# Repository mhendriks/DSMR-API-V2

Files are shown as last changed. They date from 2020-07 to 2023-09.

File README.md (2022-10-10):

</a>&nbsp;<a href="https://smart-stuff.nl/shop/" target="_blank">Buy P1 Dongle</a>

# NEW

Nu ook native ESPHome - Home Assistant integratie.
Inclusief hardware serial ondersteuning.

Er zijn hiermee meerdere keuzes mogelijk met deze hardware, namelijk:
1. DSMR-API software: met eigen opslag en web interface. ook via mqtt te koppelen met Home Assistant of andere smart home oplossingen Zie [manual/dsmr-api](manual/dsmr-api/README.md)
2. ESPHome: voor naadloze integratie met Home Assistant. Zie [manual/epshome](manual/esphome/README.md)
3. Tasmota: in ontwikkeling Zie [manual/tasmota](manual/tasmota/README.md)

# Slimmemeter P1 Dongel - versie 3.7
Eigenschappen
- hardware design voor ESPhome + DSMR API
- gebruikt secundaire seriale hardware interface (UART1) voor de beste performance
- ESP-12F (4MB) als CPU Soc
- P1 signaal inversie via BJT transistor
- 6P6C (RJ12) socket voor gemakkelijke aansluiting
- usb micro connector voor externe voeding bij SMR 4.x/3.x/2.x meters en soms bij 5.x meters
- 2 diodes voor de USB/P1 return power beveiliging
- Primaire componenten op bovenkant van de pcb makkelijk voor de smt
-  LDO met een extreem laag verlies. Resultaat minder warmteafgifte en hogere betrouwbaarheid
- DTR signaal is altijd hoog
- optie om er een watermeter dongle van te maken
- optie om er een s0 dongle (pulsteller) van te maken

## SCHEMA
Op het printje zitten de volgende modules:
- voedingscircuit: een ultra low LDO spanningsregelaar zorgt er voor dat de 5Volt naar 3.3 omgezet wordt. 
- Dikke condensator voor het opvangen van de stroompieken tijden Wifi startup
- CPU: - ESP-12F 4Mb
- level shifter: om het P1 signaal te inverteren
- USB Power: om de p1 te kunnen voeden als paracitaire voeding (uit de p1) niet kan. Bijvoorbeeld bij SMR 2/3/4 meters of sommige 5.0 meters die heel gevoelig afgesteld zijn
- watermeter: klein circuit om watermeter sensor op aan te kunnen sluiten. Dit is een spanningsdeler. In de 3.5 versie komt hier een opto coupler voor in de plaats
- J2: om de dongle te kunnen programmeren
- J1: om de dongle aan te sluiten op de p1 poort van de slimme meter

Alle modules samen zie je in het onderstaande schema.
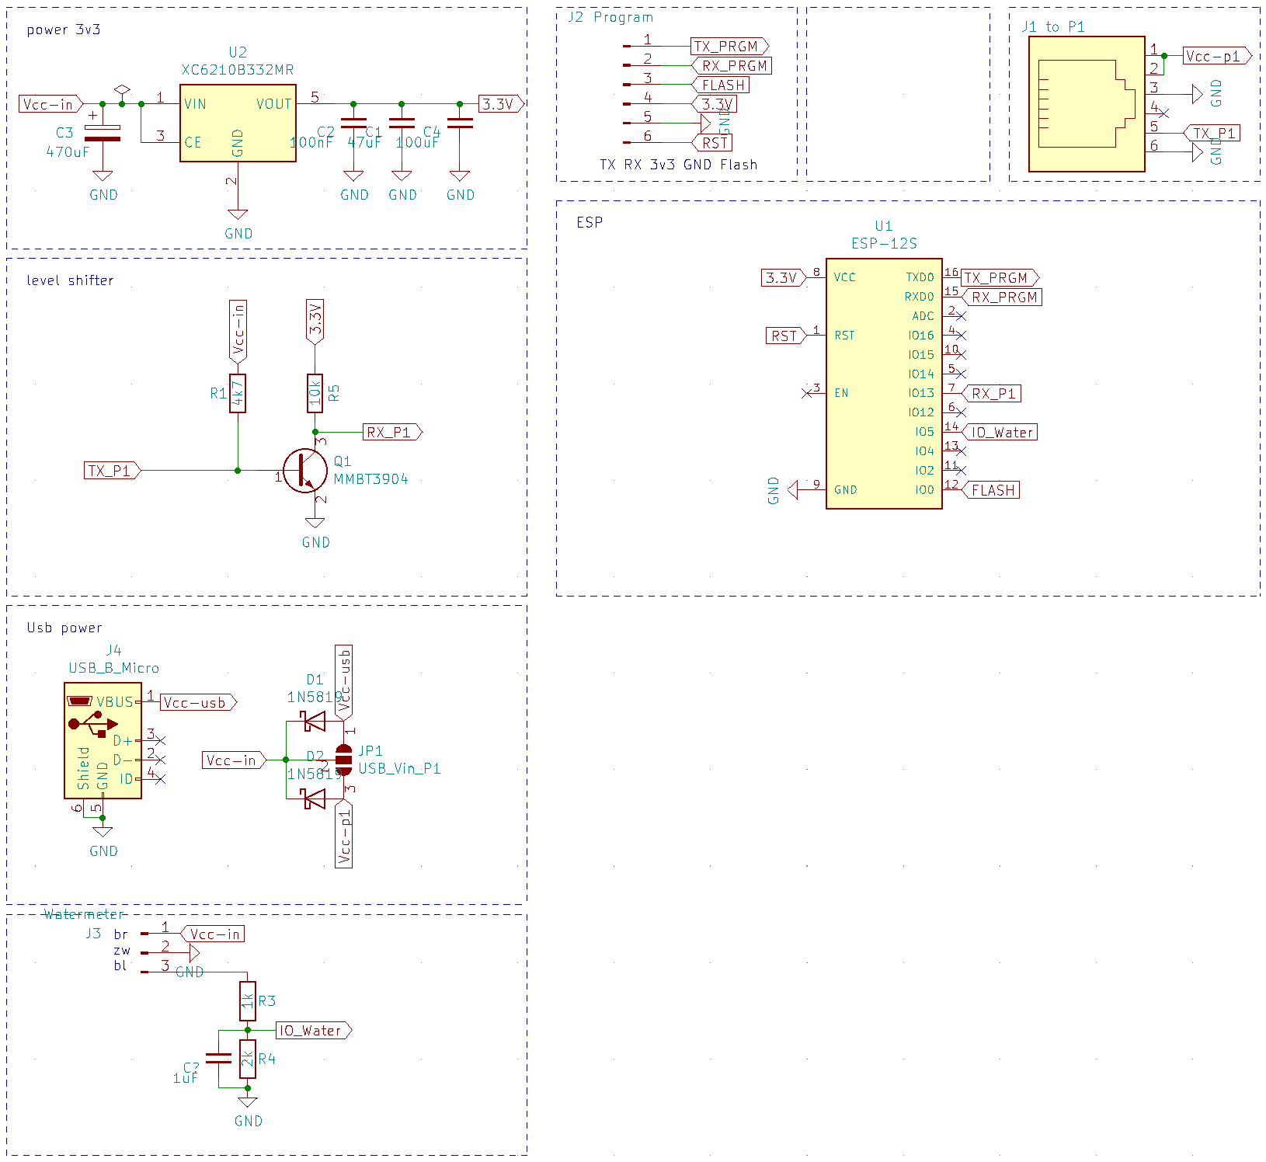
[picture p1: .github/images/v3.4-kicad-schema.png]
Kicad schema
 

Omgezet naar een pcb ziet dit er zo uit:

Bovenkant             |  Onderkant 
:-------------------------:|:-------------------------:
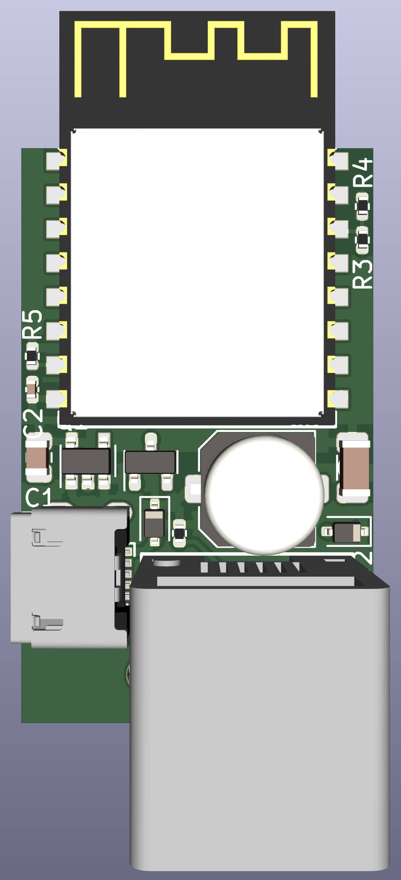
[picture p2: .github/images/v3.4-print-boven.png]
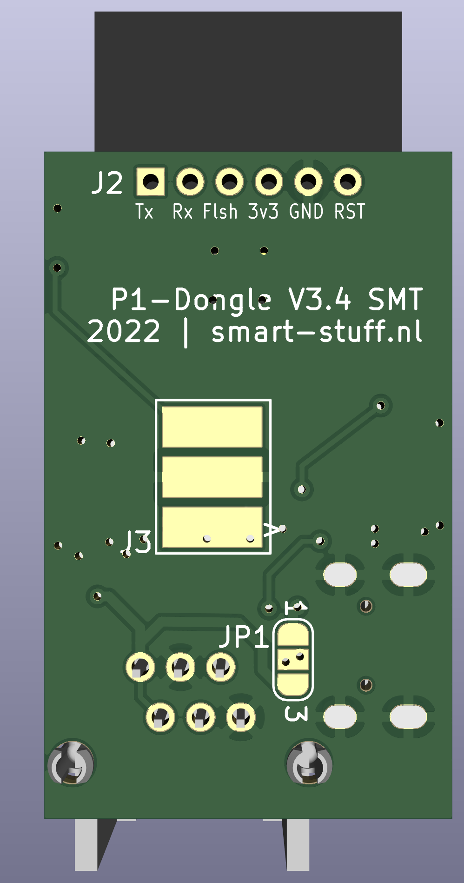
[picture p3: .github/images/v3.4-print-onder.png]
 |   

Afmeting van de print is 33 mm * 20 mm

## DSMR API SOFTWARE
Op basis van de DSMR API software van Willem aandeWiel is eerder al een doorvertaling gemaakt naar specifieke code voor de V2 en V3 hardware. Voor de V3.3 versie zijn er wederom aanpassingen gedaan met name vanwege het ontbreken van het DTR signaal. De code is hiervoor geoptimaliseerd.
Naar behoefte zou ook Tasmota of andere firmware gebruikt kunnen worden, dit is op de V3.3 versie verder niet uitgeprobeerd.

Aanpassing (tot nu toe) ten opzichte van DSMR-API van Willem zijn:
- alle statische pagina's komen uit een CDN (esp modules hebben maar een beperkte capaciteit en zijn geen hele goede webservers;)
- alle plaatjes zijn  iconen geworden en komen van een cdn
- files zijn omgezet naar Json zodat dit makkelijk te onderhouden en compacter is
- json API communicatie is ook gewijzigd (compacter en als een burst ipv gesegmenteerd)
- opmaak is zo veel als mogelijk uit de html / js files gehaald en in de css gestopt
- nieuw dashboard gemaakt
- Front-end settings worden van de dongel gelezen (een eerste aanzet)
- LittleFS in plaats van SPIFFS als bestandssysteem
- Home Assistant MQTT auto discovery 
- Watermeter uitbreiding

Uitgebreide documentatie is te vinden op: [Gitbook](https://docs.smart-stuff.nl/v/p1-dongle-api/)

## ESPHome SOFTWARE
Een hele eenvoudige manier om de dongle te koppelen aan Home Assistant is door middel van de ESPHome firmware + dsmr configuratie.
Belangrijkste voordeel is dan direct na het koppelen aan uw Wifi-netwerk begonnen kan worden met het toevoegen van de dongle in Home Assistant.

Hoe dit werkt en waar de yaml te vinden is kunt u hier lezen: [manual/esphome](manual/esphome/README.md)

# Hardware maken of aanschaffen
Je kan je eigen hardware maken of deze aanschaffen. Wil je deze aanschaffen neem dan een kijkje op <a href="https://smart-stuff.nl/shop/" target="_blank">smart-stuff.nl</a>

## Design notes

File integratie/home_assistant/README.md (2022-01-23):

# Home Assistant integratie

> LET OP! voor deze integratie dient een MQTT broker aanwezig te zijn in uw netwerk of in Home Assistant

HA maakt gebruik van de MQTT koppeling om de data vanuit de P1 dongel te ontvangen.
Om een koppeling te maken met HA dienen de volgende stappen doorlopen te worden.

>**HOME ASSISTANT AUTO DISCOVERY</br>**
> Vanaf firmware 3.2.2 is stap 1 & 2 niet meer nodig. De sensors worden automatisch door HA herkend.

1. Pas de configuration.yaml aan met extra sensors
2. Toevoegen van sensors.yaml
3. Voeg de MQTT integratie toe zodra deze niet bestaat
4. Naar behoefte dashboard + energie tabbladen configureren

**1. aanpassen configuration.yaml**</br>
Neem onderstaande code op in de `configuratie.yaml`

```
sensor: !include sensors.yaml
```

**2. Toevoegen van sensors.yaml**</br>
Voeg de `sensors.yaml` file in deze folder toe aan de HA configuratie waar ook de `configuratie.yaml` staat.

**3. Voeg de MQTT integratie toe zodra deze niet bestaat**</br>
Ga in HA naar Instellingen > Apparaten & Diensten en volg onderstaande stappen zodra MQTT integratie niet bestaat.</br>
Toevoegen MQTT integratie</br>
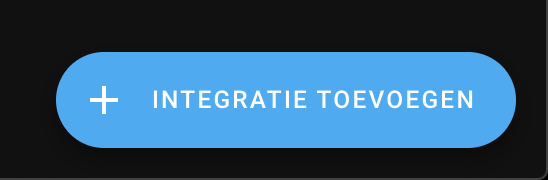
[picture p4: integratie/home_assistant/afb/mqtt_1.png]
<br>
Zoek op mqtt</br>
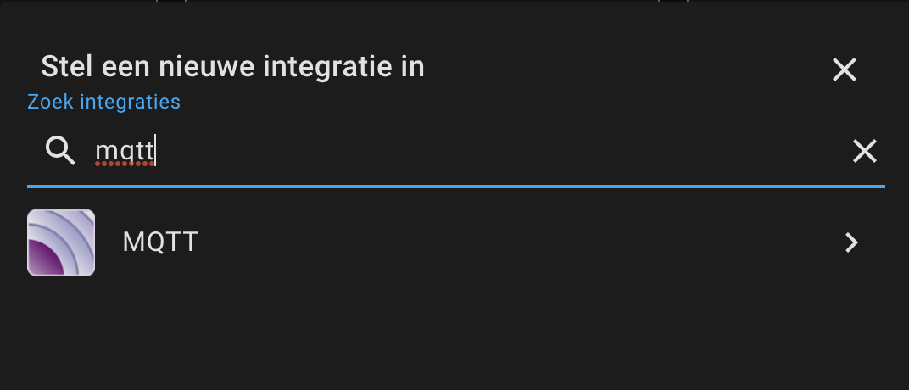
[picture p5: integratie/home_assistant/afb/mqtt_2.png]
<br>
Toevoegen broker naam/adres (192.168.2.250 is een voorbeeld)</br>
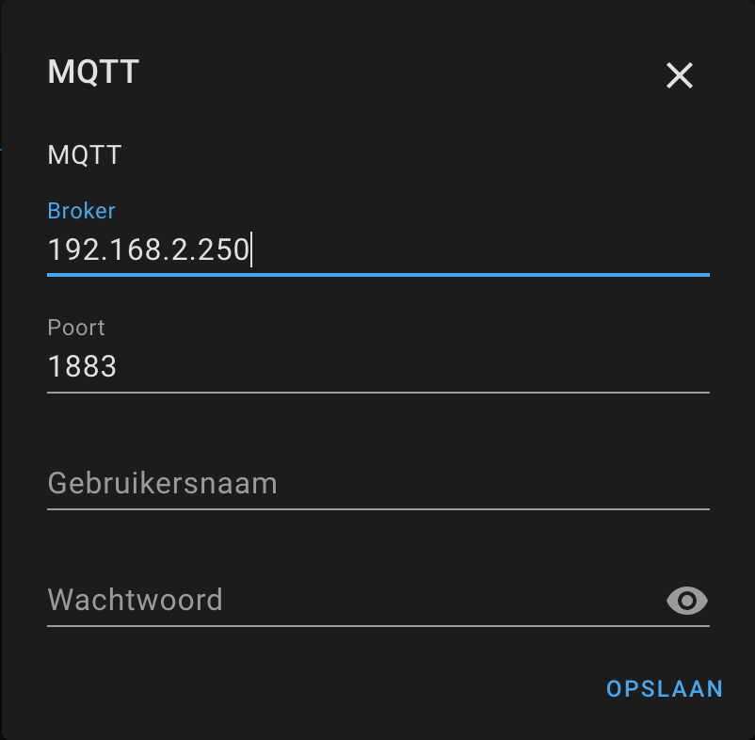
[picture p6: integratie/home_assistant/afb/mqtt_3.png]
<br>
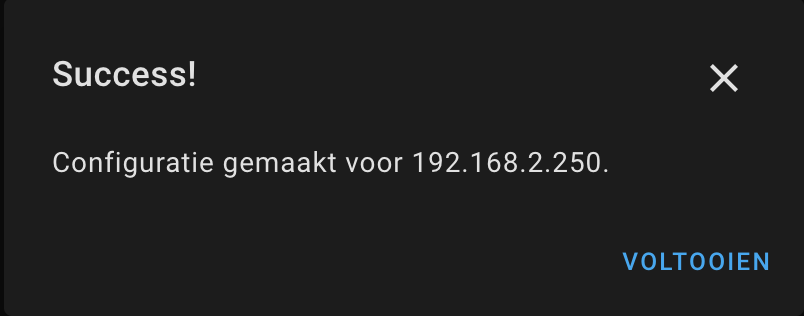
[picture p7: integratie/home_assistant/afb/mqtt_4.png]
<br>

**4. Naar behoefte dashboard + energie tabbladen configureren**</br>
Stel de verschillende tegels zelf samen en configureer de Energie tab op basis van de nieuwe entiteiten.</br>
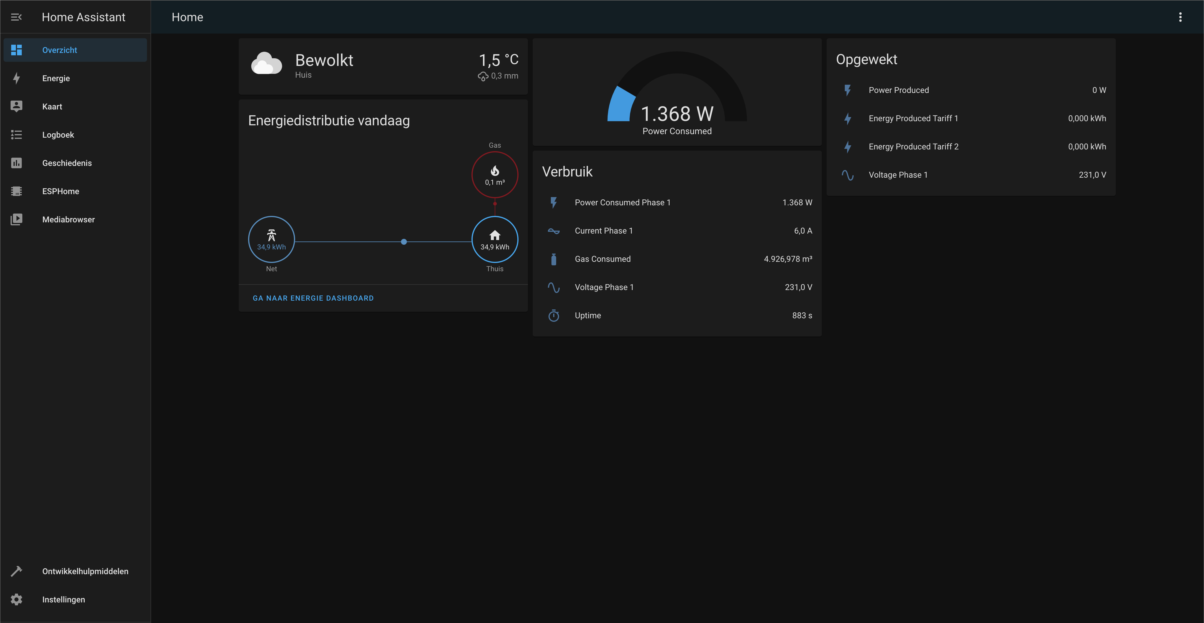
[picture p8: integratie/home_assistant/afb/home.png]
<br>

**Veel plezier met de dongle!**

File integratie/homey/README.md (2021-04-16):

# Homey integratie
Er is een Homey plugin om deze dsmr adapter op aan te sluiten deze is te vinden via: https://homey.app/nl-nl/app/com.p1.dsmr/P1-DSMR-Board-Lezer/
16-04-2021: is nu nog in testfase (https://homey.app/nl-nl/app/com.p1.dsmr/P1-DSMR-Board-Lezer/test/) en verwacht dat deze snel publiek beschikbaar komt.

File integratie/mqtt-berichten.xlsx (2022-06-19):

topic | payload
TOP TOPIC/identification | {identification":[{"value":"XMX5LGBBLA4412181356"}]}"
TOP TOPIC/p1_version | {p1_version":[{"value":"50"}]}"
TOP TOPIC/timestamp | {timestamp":[{"value":"210428201230S"}]}"
TOP TOPIC/equipment_id65] | {equipment_id":[{"value":"4530303435303033383833343439383137"}]}"
TOP TOPIC/energy_delivered_tariff1 | {energy_delivered_tariff1":[{"value":11741.29,"unit":"kWh"}]}"
TOP TOPIC/energy_delivered_tariff2 | {energy_delivered_tariff2":[{"value":12430.86,"unit":"kWh"}]}"
TOP TOPIC/energy_returned_tariff1 | {energy_returned_tariff1":[{"value":0,"unit":"kWh"}]}"
TOP TOPIC/energy_returned_tariff2 | {energy_returned_tariff2":[{"value":0,"unit":"kWh"}]}"
TOP TOPIC/electricity_tariff | {electricity_tariff":[{"value":"0002"}]}"
TOP TOPIC/power_delivered | {power_delivered":[{"value":0.703,"unit":"kW"}]}"
TOP TOPIC/power_returned | {power_returned":[{"value":0,"unit":"kW"}]}"
TOP TOPIC/voltage_l1 | {voltage_l1":[{"value":231,"unit":"V"}]}"
TOP TOPIC/current_l1 | {current_l1":[{"value":3,"unit":"A"}]}"
TOP TOPIC/voltage_l2 | {voltage_l2":[{"value":231,"unit":"V"}]}"
TOP TOPIC/current_l2 | {current_l2":[{"value":3,"unit":"A"}]}"
TOP TOPIC/voltage_l3 | {voltage_l3":[{"value":231,"unit":"V"}]}"
TOP TOPIC/current_l3 | {current_l3":[{"value":3,"unit":"A"}]}"
TOP TOPIC/power_delivered_l1 | {power_delivered_l1":[{"value":0.703,"unit":"kW"}]}"
TOP TOPIC/power_returned_l1 | {power_returned_l1":[{"value":0,"unit":"kW"}]}"
TOP TOPIC/power_delivered_l2 | {power_delivered_l2":[{"value":0.703,"unit":"kW"}]}"
TOP TOPIC/power_returned_l2 | {power_returned_l2":[{"value":0,"unit":"kW"}]}"
TOP TOPIC/power_delivered_l3 | {power_delivered_l3":[{"value":0.703,"unit":"kW"}]}"
TOP TOPIC/power_returned_l3 | {power_returned_l3":[{"value":0,"unit":"kW"}]}"
TOP TOPIC/gas_device_type | {gas_device_type":[{"value":3}]}"
TOP TOPIC/gas_equipment_id | {gas_equipment_id":[{"value":"4730303339303031373532383339333137"}]}"
TOP TOPIC/gas_delivered | {gas_delivered":[{"value":"4453.69","unit":"m3"}]}"
DSMR = default hostname (aanpassen aan je eigen hostname indien je deze zelf hebt ingesteld)

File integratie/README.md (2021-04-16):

# Integratie
Er zijn meerdere mogelijkheden om de dsmr adapter te integreren met domotica oplossing.
In de folders zijn er een paar uitgewerkt. Natuurlijk is het vooral ter inspiratie maar zeker ook om zo te gebruiken.

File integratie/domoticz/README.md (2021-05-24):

# Domoticz integratie
Om een koppeling te maken met Domoticz dienen de volgende stappen doorlopen te worden
1) ga naar je 'Domoticz/scripts/lua folder' en kopier het ...dsmr-logger.lua script hier in
2) pas daarin local DSMR_IP = "dsmr-api.local" indien de hostname van de p1 dongel gewijzgd is
3) pas de link naar de json.lue aan in regel 70 (json = ...) op basis van de plek waar deze staat. Normaal gesproken staat deze ook in de 'Domoticz/scripts/lua folder'. 
4) in de lua staat nu een minimale set aan informatie aan. Deze kan worden uitgebreid door "--" weg te halen voor het item wat getoond dient te worden
5) herlaad de Domoticz configuratie na aanpassen

**Veel plezier met de integratie!**

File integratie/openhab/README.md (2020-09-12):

# OpenHAB integratie
Hieronder twee voorbeelden voor de integratie met Tasmota en DSMR Api oplossing.
Files tref je in deze folder aan.

## Onderstaande voorbeelden zijn voor beide integraties
In file mqtt.things voeg je onderstaande toe aan je mqtt bridge.

```
	// P1 - slimmemeter P1 API implementatie
     Thing topic slimmemeter "Slimmemeter" @ "Hal" {
    Channels:
		Type string : time	"update tijd"	[ stateTopic="DSMR-API/timestamp", transformationPattern="JSONPATH:$.timestamp.[0].value" ]	
        Type number : T1     "kWh Teller 1" [ stateTopic="DSMR-API/energy_delivered_tariff1", transformationPattern="JSONPATH:$.energy_delivered_tariff1.[0].value" ]
        Type number : T2     "kWh Teller 2" [ stateTopic="DSMR-API/energy_delivered_tariff2", transformationPattern="JSONPATH:$.energy_delivered_tariff2.[0].value" ]
        Type number : P     "W"             [ stateTopic="DSMR-API/power_delivered", transformationPattern="JSONPATH:$.power_delivered.[0].value" ]   
        Type number : U     "V"        		[ stateTopic="DSMR-API/voltage_l1", transformationPattern="JSONPATH:$.voltage_l1.[0].value" ]
        Type number : I     "A"        		[ stateTopic="DSMR-API/current_l1", transformationPattern="JSONPATH:$.current_l1.[0].value" ]
        Type number : G     "m3"            [ stateTopic="DSMR-API/gas_delivered", transformationPattern="JSONPATH:$.gas_delivered.[0].value" ]     
    }
    
// P1 - slimmemeter Tasmota implementatie
     Thing topic slimmemeter_tas "Slimmemeter" @ "Hal" {
    Channels:
		Type string : p1	"receive data"	[ stateTopic="tele/tasmota_C3C439/RESULT", transformationPattern="JSONPATH:SSerialReceived" ]	
    }
  
``` 
    
in de rules folder maak je een nieuw bestand aan p1-dsmr.rules met onderstaande code. 
```
// Alleen nodig voor de Tasmota
rule "P2 P"
when
    Item P2 received update
then
	if (P2.state == NULL || P2 == "") return;
    var rawString = P2.state.toString
	//P1_I 		1-0:31.7.0(002*A)
	val rawString3 = transform("REGEX", ".*([0-9]{3}).A.*", rawString)
	if ( rawString3 != NULL && rawString3 !== null && rawString3 != "") { 
		P1_I.postUpdate(rawString3) 
		} 
	//P1_T1		1-0:1.8.1(000013.000*kWh) (Totaal geleverd tarief 1 (nacht))
	 rawString3 = transform("REGEX", ".*1.8.1.([0-9]{6}.[0-9]{3}).kWh.*", rawString)
	if ( rawString3 != NULL && rawString3 !== null && rawString3 != "") { 
		P1_T1.postUpdate(rawString3) 
		} 
	//P1_T2 	1-0:1.8.2(000084.000*kWh) (Totaal verbruik tarief 2 (dag))
	 rawString3 = transform("REGEX", ".*1.8.2.([0-9]{6}.[0-9]{3}).kWh.*", rawString)
	if ( rawString3 != NULL && rawString3 !== null && rawString3 != "") { 
		P1_T2.postUpdate(rawString3) 
		} 
	//P2_GAS 	0-1:24.2.1(191222151005W)(02728.449*m3)
	rawString3 = transform("REGEX", ".*[0-9]{12}.*([0-9]{5}.[0-9]{3}).m3.*", rawString)
	if ( rawString3 != NULL && rawString3 !== null && rawString3 != "") { 
		P1_GAS.postUpdate(rawString3) 
		} 
	// P2_P 		1-0:21.7.0(00.523*kW)
	rawString3 = transform("REGEX", ".*21.7.0.([0-9]{2}.[0-9]{3}).kW.*", rawString)
	if ( rawString3 != NULL && rawString3 !== null && rawString3 != "") { 
		P1_P.postUpdate(rawString3) 
		} 
		//time: 0-0:1.0.0(200716222227S)
	rawString3 = transform("REGEX", ".*1.0.0.([0-9]{12})S.*", rawString)
	if ( rawString3 != NULL && rawString3 !== null && rawString3 != "") { 
		P1_time.postUpdate(rawString3) 
		} 
end

//Voor Tasmota en API 
rule "P1 last update" //convert time to normal readable time
when
    Item P1_time received update
then
	if (P1_time.state == NULL || P1_time == "") return;
    var rawString = P1_time.state.toString
	val res = String::format("%s-%s-%s %s:%s:%s", rawString.substring(4, 6), rawString.substring(2, 4), rawString.substring(0, 2),rawString.substring(6, 8), rawString.substring(8, 10),rawString.substring(10, 12))
	if ( res != NULL && res !== null && res != "") { 
		P1_tijd.postUpdate(res) 
		} 
end   
``` 

In het .items bestand voeg je de waardes toe die je wilt zien. Hieronder een voorbeeld (dit voorbeeld is voor tasmota + standalone implementatie geschikt).
```
Number P1_P "Actueel vermogen [%s]"	 {channel="mqtt:topic:mosquitto:slimmemeter:P" } 
Number P1_GAS "Gasmeter: [%.1f]"	 {channel="mqtt:topic:mosquitto:slimmemeter:G" }
Number P1_T1 "kWh Teller 1: [%s]"	 {channel="mqtt:topic:mosquitto:slimmemeter:T1" } 
Number P1_T2 "kWh Teller 1: [%s]"	 {channel="mqtt:topic:mosquitto:slimmemeter:T2" } 
Number P1_I "Stroom: [%s]"			 {channel="mqtt:topic:mosquitto:slimmemeter:I" }
Number P1_U "Spanning: [%s]"		 {channel="mqtt:topic:mosquitto:slimmemeter:U" } 
String P1_time "tijd: [%s]" 		 {channel="mqtt:topic:mosquitto:slimmemeter:time" } //dit is de systeemtijd uit de slimmemeter
String P1_tijd "tijd: [%s]"

String P2 "tasmota only [%s]"				 {channel="mqtt:topic:mosquitto:slimmemeter_tas:p1" } 
```

In het .sitemap bestand laat je de waardes uit .items terugkomen
```
Frame label="Slimmemeter" {
    Text item=P1_T1 label="kWh Teller Dal: [%.1f kWh]"
    Text item=P1_T2 label="kWh Teller Normaal: [%.1f kWh]"
    Text item=P1_P label="Actuele vermogen: [%.3f kW]"
    Text item=P1_I label="Actuele stroom: [%.0f A]"
    Text item=P1_U label="Actuele Spanning: [%.1f V]"
    Text item=P1_GAS label="Gasmeter: [%.1f m3]"
   	Text item=P1_tijd label="Laatste P1 update: [%s]"
   	Text item=P1_time label="Laatste P1 update: [%s]" 
   	}
```

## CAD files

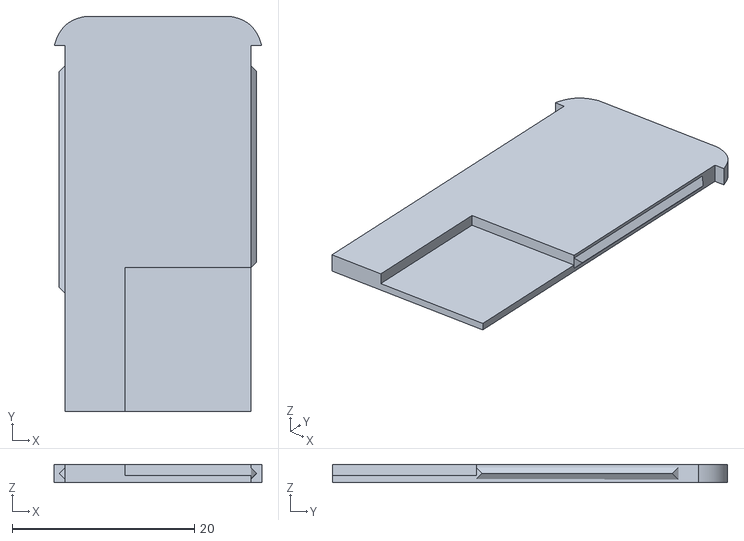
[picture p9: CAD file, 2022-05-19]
case/3.6_onder.stl
22.8 x 43.4 x 2.00

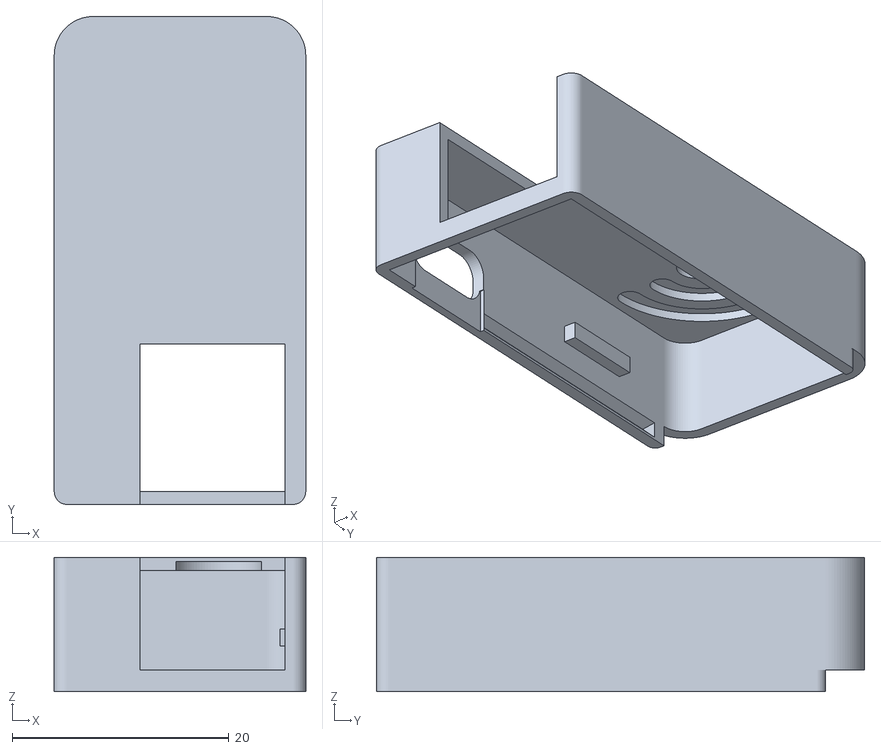
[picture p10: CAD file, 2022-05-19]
case/v3.6 boven.stl
23.2 x 45.0 x 12.4

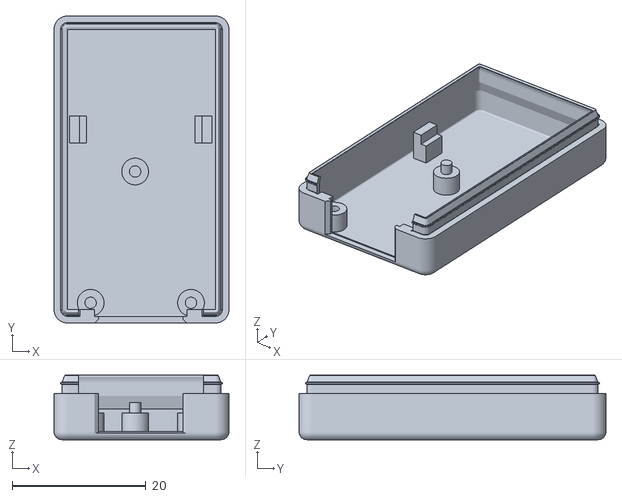
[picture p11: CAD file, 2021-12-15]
case/V3.3_onder_usb.stl
26.2 x 45.9 x 9.65

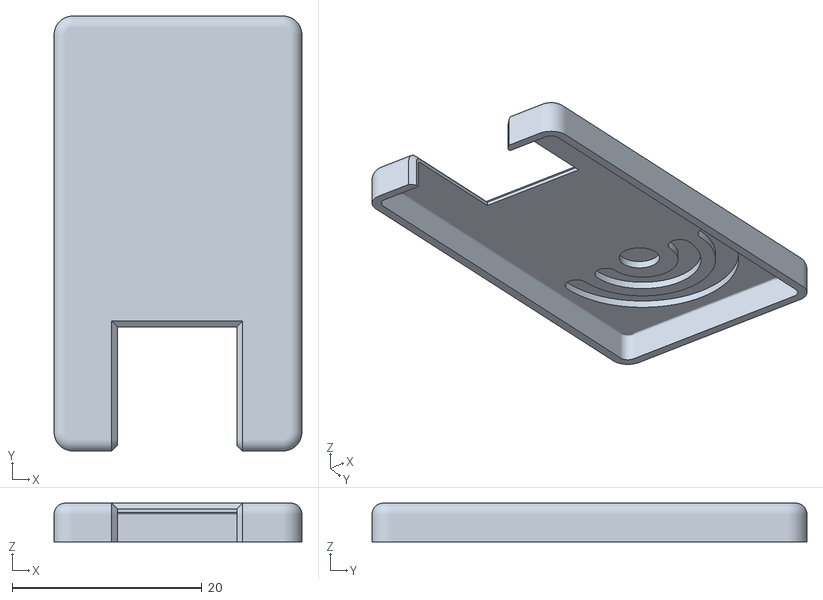
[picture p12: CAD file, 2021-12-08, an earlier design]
case/v3.3 boven.stl
26.2 x 45.9 x 4.10

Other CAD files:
case/v3.3 onder.stl

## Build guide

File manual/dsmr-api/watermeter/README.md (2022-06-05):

# **P1 + Waterlezer dongel (ESP32)**

Dit document beschrijft de installatie en configuratie van de Watermeter Dongel op ESP32 hardware. De hardware komt met werkende software. De Dongel dient te worden aangesloten op de slimme meter en watermeter. Wil je deze aanpassen ga dan naar het onderdeel Flashen.<br>

## **LED functie**<br>
De dongel is uitgerust met een blauwe LED. Deze heeft meerdere functies, namelijk:
- na inpluggen zal de LED ca 1.5 seconde oplichten. Is dit niet het geval dan is er een probleem met stroom of met de dongel
- Zodra de dongel WiFi connectie heeft zal de LED blijven branden.
- Tijdens het lezen van een datapakket zal de LED kortstondig uit of aan gaan. Indien er Wifi verbinding is gaat de LED kort uit. Indien er geen Wifi is zal de LED kort aan gaan.

## **USB voeding**<br>
USB adapter bij een P1 + Waterlezer dongle is noodzakelijk. In combinatie met de slimme meter zal het soms mogelijk zijn om de 5.0  slimme meter de dongel te laten voeden. <br>
>**TIP**<br>
>De USB adapter mag een oude smartphone of tablet adapter zijn of een usb aansluiting die voorhanden is in de meterkast (bv van een NAS/Router). Bijna alle voedingen voldoen (5V/5Watt is prima).<br>

## **Monteer de sensor op de watermeter**<br> 
Watermeters met een metalen plaatje op de kleine wijzer zijn geschikt voor deze set. Het is zaak om de sensor recht boven deze wijzer te plaatsen zonder dat er lucht/plakband tussen de sensor en de wijzer zit. Afstand tussen wieltje en sensor dient zo klein mogelijk te zijn voor de meest accurate opname.<br>
<br>
Ook dient de sensor zo te zitten dat deze 1 keer per omwenteling een signaal opneemt. Dit kan je aan de sensor zien doordat het rode lampje gaat branden. Sensor zit normaal gesproken recht boven deze wijzer maar dan iets verschoven van het midden van deze wijzer.
Maak de sensor vast met meegeleverde klittenband of met de sensor houder, zie onderstaande montage wijze.



>**TIP**<br>
>- Zet de kraan een beetje open om te checken of de sensor goed zit (rode ledje gaat dan per omwenteling 1x aan).<br>
>- Monteer de sensor met het kruis / rode ledje naar de wijzerplaat toe.

**Configuratie dongle**<br>
Onderstaande stappen dienen gevolgd te worden.<br>
- sluit usb adapter aan via een usb micro kabel
- de LED van de dongle licht op en de dongle start op
- wacht 20 seconden en zoek op PC/laptop/smartphone/tablet naar wifi hotspot (p1-dongle) en klik deze aan
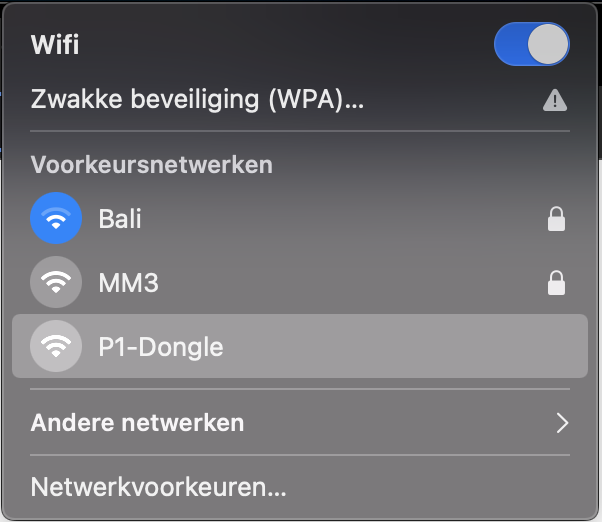
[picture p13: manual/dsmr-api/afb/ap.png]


- Verbind met de hotspot

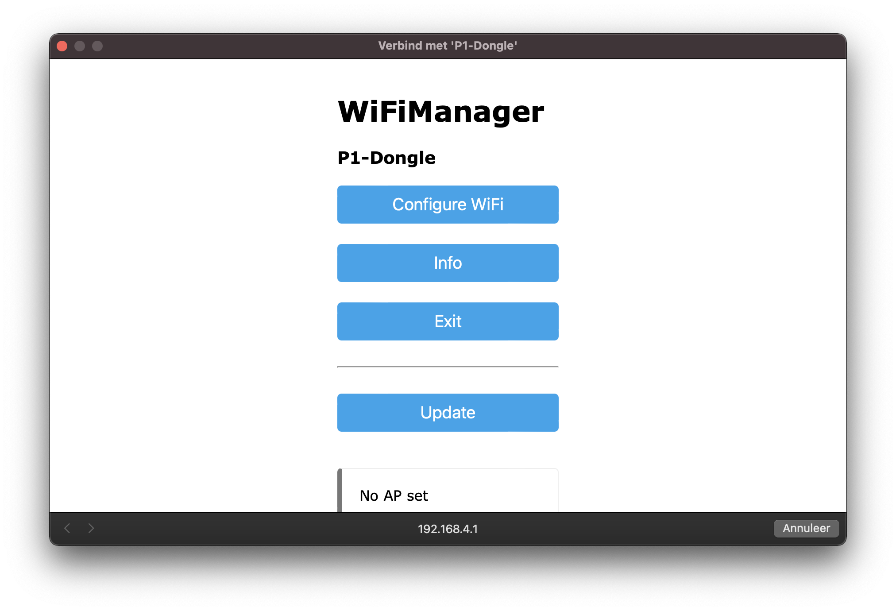
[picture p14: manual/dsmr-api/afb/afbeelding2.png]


- Klik op &quot;Configuratie Wifi&quot;

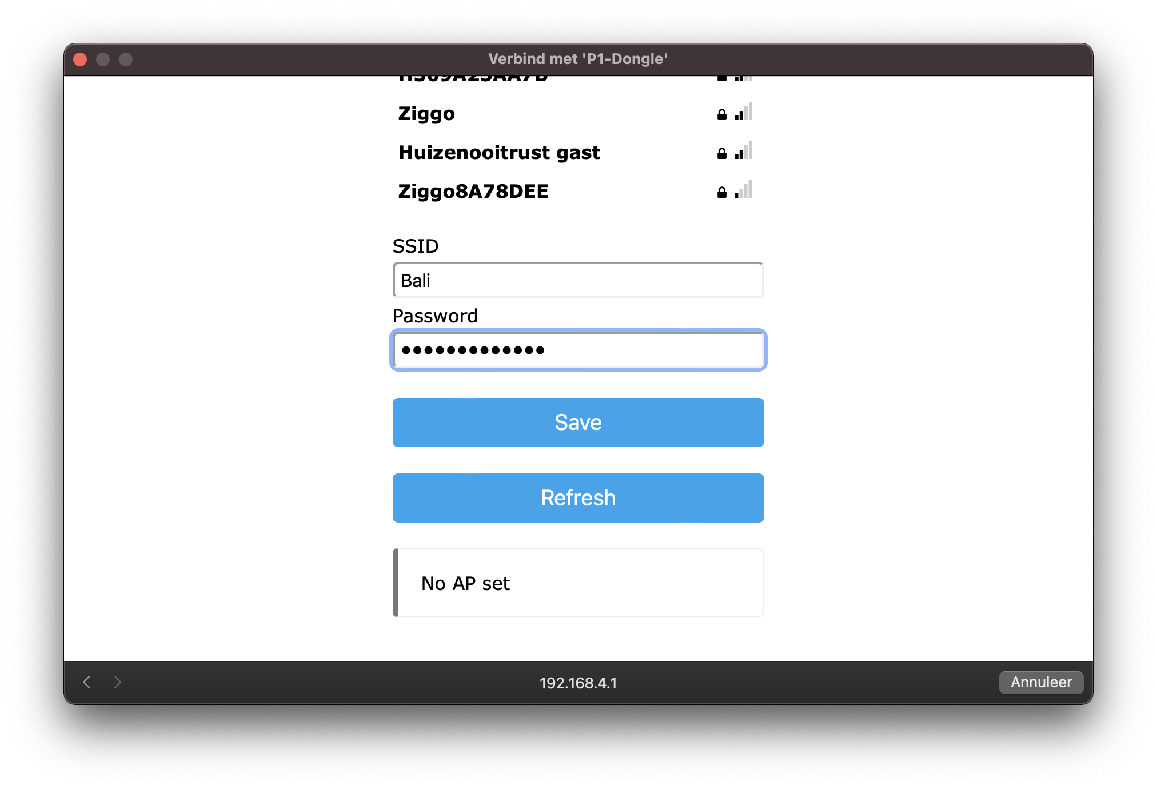
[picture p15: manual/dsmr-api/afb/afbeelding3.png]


- Klik op het uw netwerknaam en vul daarna het bijbehorende en **wachtwoord** in bij Password.
- Druk op &quot;Save&quot;
- Adapter zal op nieuwe opstarten en u kunt het scherm sluiten.

Vanaf dit moment zal de adapter te vinden zijn via: [http://p1-dongle.local/](http://p1-dongle.local/) 

Deze naam is aanpasbaar via settings in de dongle.

##**Aansluiten Sensor**<br>

## **Uitlezen Slimmemeter**<br>
Er zijn drie manieren om via de dongel de slimmemeter uit te lezen, namelijk:

1. Via de webinterface van de Slimme meter ([http://p1-dongle.local/](http://p1-dongle.local/))
2. Via de rest api ([http://p1-dongle.local/api/v2/hist/hours](http://p1-dongle.local/api/v2/hist/hours)); zelf ophalen van de gegevens op gewenste moment; zie API info in de webinterface voor meer informatie
3. Via MQTT; dongel pusht elke x seconde de gegevens naar de mqtt broker; zie hieronder de configuratie van mqtt

## **Webinterface**<br>
Het hoofdscherm opent met onderstaande pagina. Kan zijn dat de tabel nog leeg is in de eerste 30 seconden na opstarten.

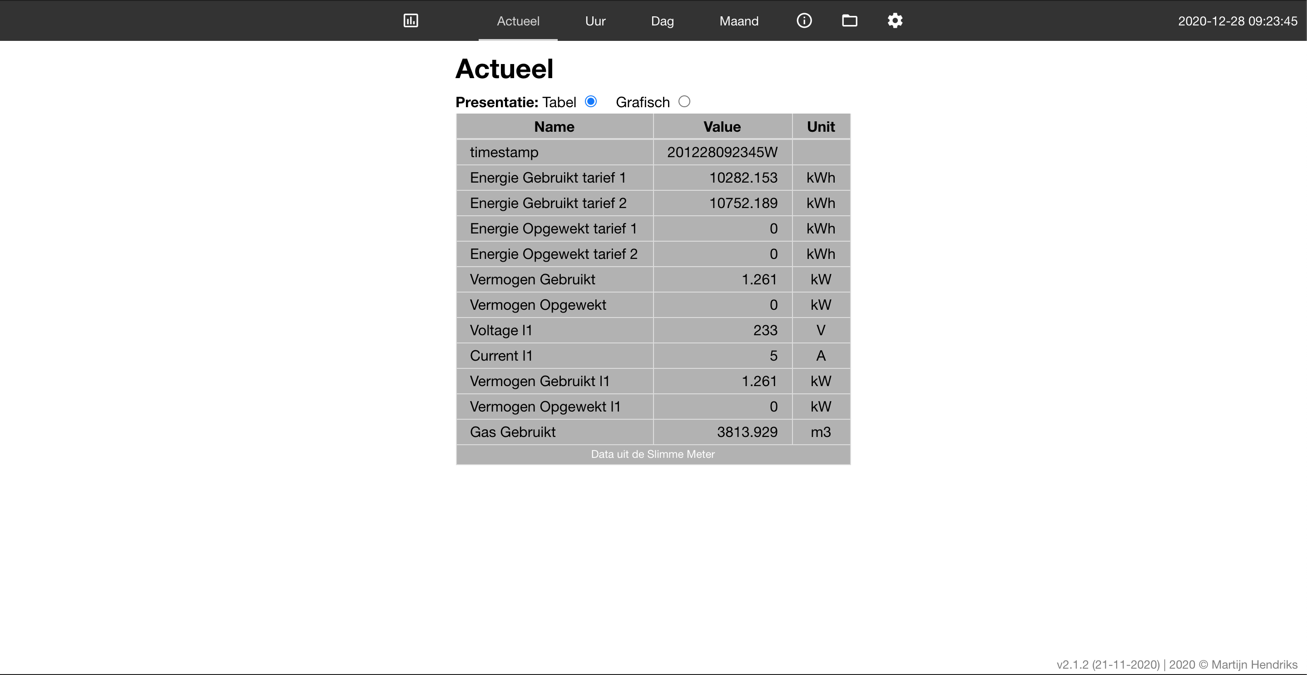
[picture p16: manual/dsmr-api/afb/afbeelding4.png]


In de menu zijn de volgende opties opgenomen

1. Actueel: samenvatting van de verschillende grootheden
2. Per Uur / Per Dag / Per Maand: de verbruikscijfers weergegeven per dag/maand/jaar
3. Telegram: ruwe data uit de slimme meter
4. All Fields: alle slimme meter data netjes geformateerd
5. Systeem info: informatie over de adapter zoals versie, capaciteit
6. APIDocs: informatie over de mogelijkheid om de gegevens op afstand te kunnen uitlezen
7. File symbool: kunnen de bestanden op de adapter geraadpleegd/verwijderd of geupload worden
8. Wieltje: systeeminstellingen.

## **Configuratie**<br>
Open in de browser [http://dsmr-api.local/](http://dsmr-api.local/)
Druk op het wieltje rechts in het menu. Het onderstaande settingsscherm is zichtbaar.
Vul onderaan de beginstand van de watermeter in en druk op Opslaan. 

>**LET OP**<br>
> Meters met 2 rode cijfers dienen ingevoerd te worden met een 0 achter de laatste cijfer. Dus 34.23 wordt ingevoerd als 34 m3 + 230 liter

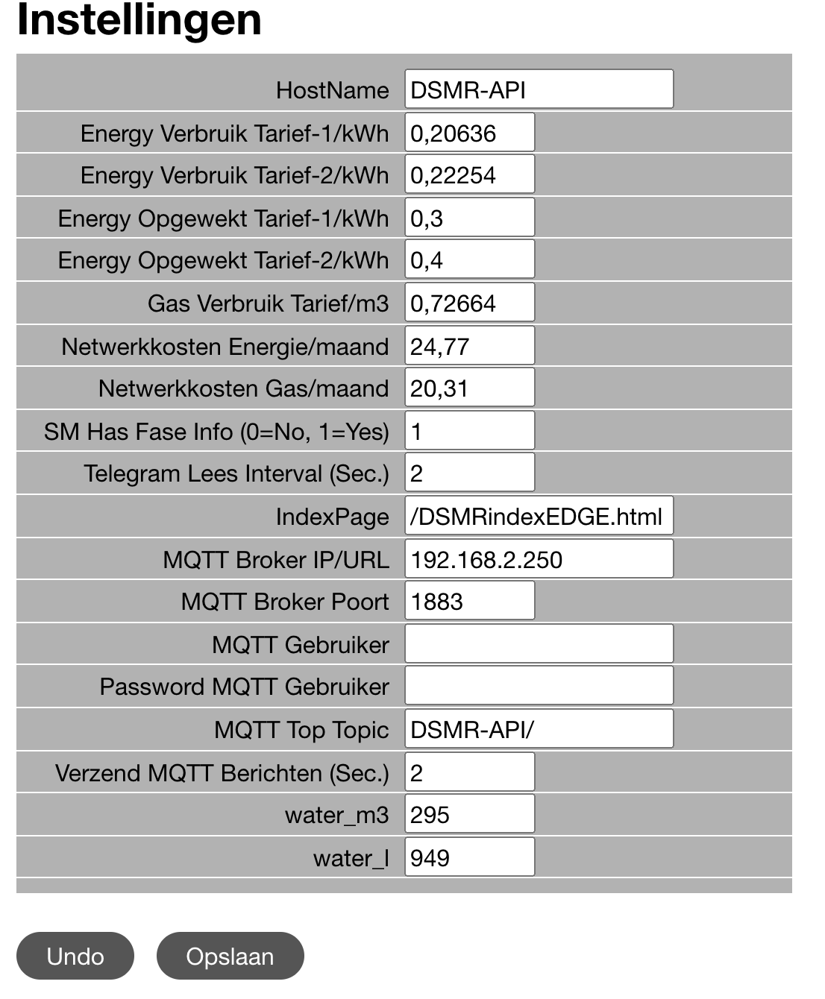
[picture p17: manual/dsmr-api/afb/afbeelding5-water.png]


## **Watermeters met 10 liter wieltje!**<br>
Heeft u een watermeter met een wieltje wat 10liter per omwenteling registreert dan dient de settingsfile van de dongle aangepast te worden. Volg de onderstaande stappen.
1. open http://p1-dongle.local/#FileExplorer in uw browser
2. download de DSMRsettings.json file
3. pas ```"waterfactor":1``` aan naar ```"waterfactor":10```
4. upload de aangepaste settingsfile en start de dongle opnieuw op

1 - MQTT

Voor het activeren van de mqtt interface dient het onderstaande ingesteld te worden.

1. HostName (mqtt broker)
2. MQTT Broker IP/URL: (bv: 192.168.2.250)
3. Port (default: 1883)
4. MQTT Top Topic van deze adapter (default: DSMR-API)
5. Optioneel: wachtwoord en Username
6. Verzenden MQTT berichten: in welke frequentie de berichten verzonden worden. In dit voorbeeld elke 2 seconden terwijl de leesfrequentie 10 seconden is. Beetje onzinnig de huidige instelling ;-) aangezien er dan 5 x dezelfde waarde verzonden wordt.
7. Op Opslaan drukken rechtsboven om de settings op te slaan en mqtt te activeren

2 – Tarieven

In hetzelfde settingsscherm zijn ook de tarieven in te vullen zodat bij de kostenberekening de bedragen komen te staan. Pas deze aan op basis van je contract met je energie leverancier.

Let op! de bedragen in de adapter kunnen afwijken van je echte nota en zijn daarom indicatief

3 - watermeter 
In de laatste 2 velden kan de watermeter stand ingevuld worden of worden geupdate.

4 – Overige instellingen

De frequentie van uitlezen kan ingesteld worden.

Daarnaast ook de frequentie van toesturen van de MQTT gegevens.

## **Remote update**<br>
Dit kan op twee manieren, namelijk
1) via Telnet door U + <return> in te typen en daar na versie nummer (bv 4.2.3) + <return>. Vanaf 4.2.0 versie is de watermeterfunctie standaard aanwezig in de firmware.
2) via de webinterface door de functie aanroep + versie op te geven. Bijvoorbeeld: /remote-update?version=4.2.3

Ook Filesysteem update is mogelijk via telnet. Dit door S <return> versie <return> in te voeren. 
Standaard zal er geupdate worden van de ota.smart-stuff.nl directory. Deze verwijzing kan worden aangepast in de settingsfile op de dongel. 

>Let op: er kan alleen verwezen worden naar http servers.

## **Flashen**<br>
Flashen dient via een USB - TTL adapter te gebeuren. Op J2 (onderkant) zitten de aansluitingen voor deze interface. 

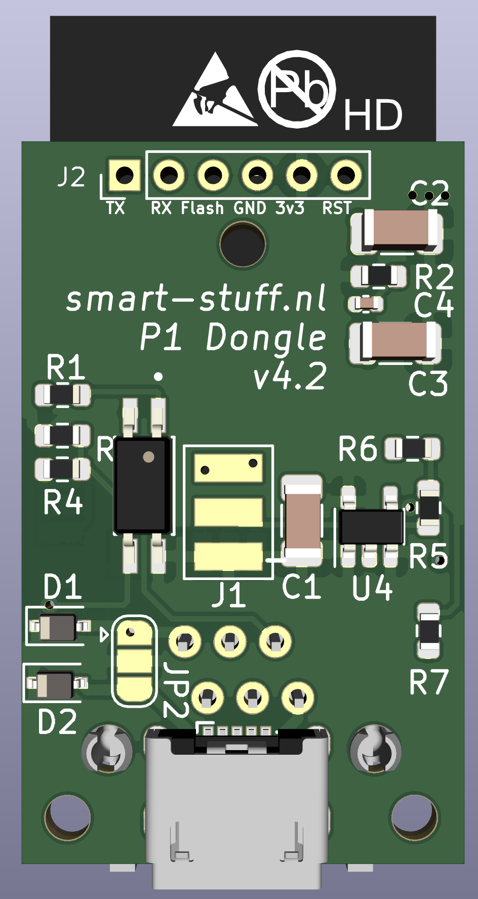
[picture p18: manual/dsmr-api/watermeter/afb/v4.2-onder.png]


1. RX
2. TX
3. Flash
4. GND
5. 3.3Volt
6. Reset

De software is te vinden op [https://github.com/mhendriks/P1-Dongel-ESP32/releases](https://github.com/mhendriks/P1-Dongel-ESP32/releases)

>**LET OP!<br>
>Dongle altijd loskoppelen van voeding / slimme meter wanneer deze wordt geflasht**

**Meest voorkomende problemen**<br>
*Hotspot (P1-Dongel) niet of kort zichtbaar</br>*
De basic dongel wordt gevoed door de slimme meter. Afhankelijk van het merk / type is de stroomlevering kritischer. 
De dongel zal bij de eerste aanmelding de omgeving scannen en zijn netwerk instellen. Dit kost kortstondig veel stroom en enkele meters zullen dit niet accepteren en de voeding stoppen. Gevolg is dat de dongel steeds op nieuw gaat starten (LEDje knippert).
Neem in z'n geval contact met mij op om de dongel te ruilen voor een exemplaar met extra usb aansluiting. Vaak is het alleen nodig om de usb voeding tijdens de eerste start aan te sluiten. Daarna kan deze verwijderd worden. Let op! valt de stroom uit dan kan het nodig zijn om de usb voeding weer te gebruiken.

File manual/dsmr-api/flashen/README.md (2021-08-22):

# **Software updates**
De Dongle kan op verschillende manieren van nieuwe firmware/data voorzien worden. Meest gebruikelijke manieren zijn:
1. Over The Air (OTA) update via de webinterface
2. Flashen via een FTDI adapter

Advies is om allereerst een OTA update te proberen. Mocht dit niet lukken of mislukken dan zou daarna een update via de FTDI adapter uitgevoerd kunnen worden.

**OTA update**
De update pagina van de webinterface is in de firmware aanwezig zodat deze altijd aangeroepen kan worden indien de module opstart. Het aanroepen van de gaat via deze  url: http://dsmr-api.local/update

Er wordt dat een update pagina getoond, zie hieronder. Is dit niet het geval, update dan de module via de FTDI adapter methode.

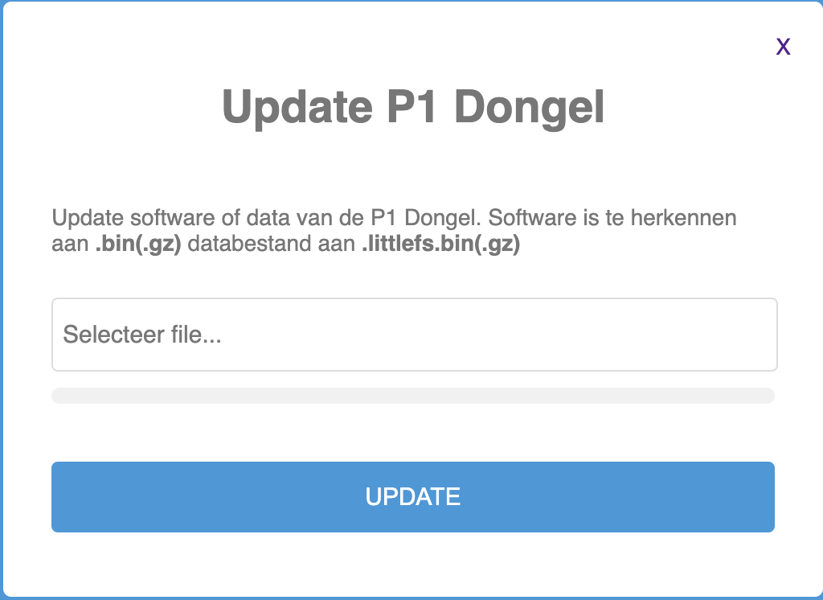
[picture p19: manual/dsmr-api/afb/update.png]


Er kunnen twee soorten updates uitgevoerd worden, namelijk:
1. file systeem: opnieuw alle bestanden op de dongle zetten. herkenbaar aan bestandsnaam .spiffs.bin(.gz) of vanaf de 3.0.0 versie -> .littlefs.bin(.gz)
2. firmware: opnieuw/update van de software. herkenbaar aan bestandsnaam .bin(.gz)

Vanaf de 3.0.0 versie kan een van de bestanden geupload worden en de module herkent zelf welk type dit is. Voor de 2.x.x versie dient firmware en file system bestanden via de beschikbare opties in het upload scherm worden aangeboden.
Na het klikken op UPDATE wordt het bestand geupload, de software geinstalleerd en volgt er een reboot. Dit proces kan enkele minuten duren.

**Flashen via FTDI adapter**

Flashen dient via een FTDI interface te gebeuren (115200 baud). Op J2 zitten de aansluitingen voor deze interface. 
De pinout is :

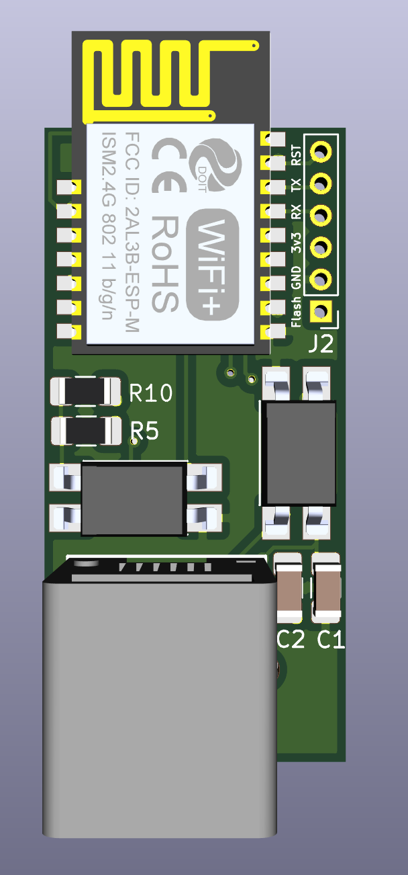
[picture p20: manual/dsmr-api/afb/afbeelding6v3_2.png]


1. Flash (vierkante pad / Rode pijl); Flash op GND en opnieuw opstarten om in de program mode te komen
2. GND
3. 3.3Volt
4. RX
5. TX
6. Reset (indien deze tegen GND aangehouden wordt zal de module resetten)

De firmware/file system bestanden zijn te vinden op [https://github.com/mhendriks/DSMR-API-V2](https://github.com/mhendriks/DSMR-API-V2)

**LETOP!!! afhankelijk van je hardware zijn er modules met 1,2 of 4Mb geheugen. Het is belangrijk om de juiste bestanden/instellingen te gebruiken bij het updaten van de software. Op de Systeeminformatie pagina staat bij Real Chip Size de geheugenomvang.**

Hardware in download modus zetten. Dit doe je zo:
1. Flash poort aan GND koppelen
2. Daarna de RESET poort aan GND koppelen en na 1 seconden weer losmaken (Flash blijft nog op GND)
3. na upload van de firmware Flash losmaken en module Resetten via Reset. 

Bij elke update stappen 1 tot 3 doorlopen.

Voor het flashen kan de Arduino IDE gebruikt worden echter dit kost behoorlijk wat setup inspanning. Eenvoudiger is om de Esptool te gebruiken.

Voorbeeld 2Mb versie flashen ***file system***.
- MacOS voorbeeld
- gebruik python3
- upload script van de Arduino 
- let op! poort zelf even juist instellen
- write_flash 0x1F0000 = 2Mb, 0xEB000 = 1Mb
- bijvoorkeur de .gz versies gebruiken omdat daar de upload sneller bij gaat (kans kleiner op een verstoring)

```
python3 ~/Library/Arduino15/packages/esp8266/hardware/esp8266/2.7.4/tools/upload.py --chip esp8266 --port /dev/cu.usbserial-A50285BI --baud 115200 --before default_reset --after hard_reset write_flash 0x1F0000 DSMR-API-V2.3_2Mb.spiffs.bin.gz
```

Voorbeeld flashen ***firmware*** (geheugenomvang is hierbij niet belangrijk voor de upload tool)
```
python3 ~/Library/Arduino15/packages/esp8266/hardware/esp8266/2.7.4/tools/upload.py --chip esp8266 --port /dev/cu.usbserial-A50285BI --baud 115200 --before default_reset --after hard_reset write_flash 0x0 DSMR-API-V2.3.6_2Mb.bin.gz
```

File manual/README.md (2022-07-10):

# **Slimmemeter P1 Dongel**

De documentatie is verplaatst naar Gitbook.<br>

DSMR-API<br>
[P1-Dongle-Pro](https://docs.smart-stuff.nl/)<br>
[P1-Dongle](https://docs.smart-stuff.nl/v/p1-dongle-api/)
<br>
<br>
ESPHOME<br>
[P1-Dongle-Pro](https://docs.smart-stuff.nl/v/esphome-p1-dongle-pro/)<br>
[P1-Dongle](https://docs.smart-stuff.nl/v/esphome-dongle/)

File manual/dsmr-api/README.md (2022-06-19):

# **Slimmemeter P1 Dongel**

De documentatie is verplaatst naar :<br>
[P1-Dongle-Pro](https://docs.smart-stuff.nl/)<br>
[P1-Dongle](https://docs.smart-stuff.nl/v/p1-dongle-api/)

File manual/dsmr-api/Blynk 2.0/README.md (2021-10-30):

# **Blynk 2.0 App**

Deze functie is beschikbaar vanaf release 3.1.1 van de dsmr V3 firmware.

In de Blynk app kunnen diverse gegevens gedeeld worden zodat actuele gegevens overal en altijd zichtbaar zijn. 
Deze gegevens lopen via de Blynk Cloud Service. Er is geen link tussen het soort gegevens en de inhoud omdat het virtuele veldnamen (V1 - V11) zijn maar het is wel goed om te weten dat deze data via dit platform verloopt.

**Blynk app instellen** 

Stap 1: Download de Blynk app uit de app store.

[Blynk voor Android](https://play.google.com/store/apps/details?id=cloud.blynk)  
[Blynk voor iOS](https://apps.apple.com/us/app/blynk-iot/id1559317868) 

Stap 2: maak een Blynk Account
Via Blynk Console of app maakt u een Blynk Account. Advies is om dit via [Blynk Console](https://blynk.cloud/dashboard/login) te doen ivm de stappen hierna.

Stap 3: Instellen Blynk : Template
Bij het scherm QuickStart klikt u op [CANCEL]

In het menu klikt u op Template en daarna op [New Template]
- Name : P1 Dongel
- Hardware : ESP8266
- Connection Type: Wifi
Klik dan op [Done]

Klik in het overzichtscherm op [Save] rechtsboven

Stap 4: Instellen Blynk : Device
Klik op het vergrootglas (Search)
Klik op [New Device]
Klik op [From Template]
TEMPLATE: P1 Dongle
Klik op [Create]

kopieer de gegevens in het rechtervenster zoals het voorbeeld hieronder:
#define BLYNK_TEMPLATE_ID "TMPLPuW-DEMO"
#define BLYNK_DEVICE_NAME "P1 Dongel"
#define BLYNK_AUTH_TOKEN "2V-AJxupJf6uSGUDcXMjnh_zDEMO"

Stap 5: creëer Datastreams
Klik op de ... (menu) achter P1 Dongle (offline) zoals hieronder en daarna op Edit Dashboard.
Klik dan op [Datastreams]
Klik op [+New Datastreams] -> [VirtualPin]
Vul onderstaande in:
Name: Energie-Geleverd
Alias: Energie
PIN : V0
Data type: Integer
Units: Watts
Min: 0 
Max: 999999
Klik daarna op [Create]

herhaal bovenstaande voor de overige VirtualPins.

Druk dan op [Save] + [update 1 active device]

Stap 6: creëer Dashboard
Klik op de ... (menu) achter P1 Dongle (offline) zoals hieronder
en daarna op Edit Dashboard

**New account**  
Indien u de Blynk app voor eerst gebruikt dan dient u een account aan te maken. 

**Start nieuw project**  
Druk op het scan icoon (rode pijl) in de Blynk app.

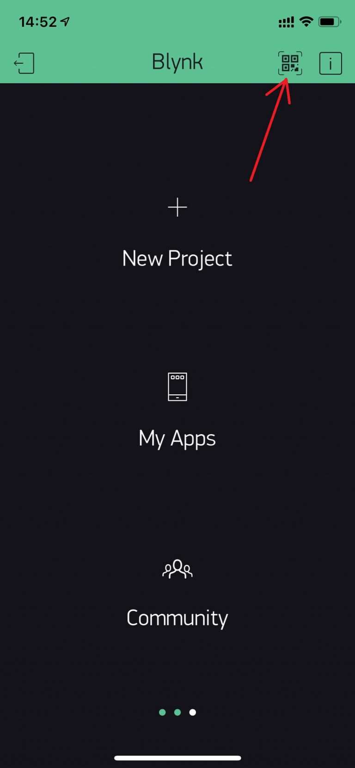
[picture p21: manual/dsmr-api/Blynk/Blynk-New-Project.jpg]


**scan qr code**  
Scan onderstaande qr code met de Blynk App.

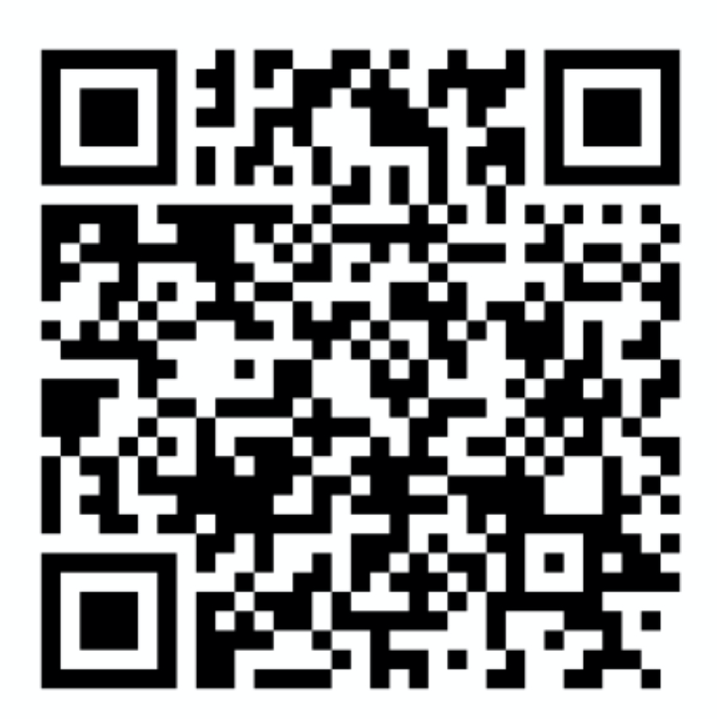
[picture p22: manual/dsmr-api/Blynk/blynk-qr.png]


**copier/e-mail auth token voor in de P1 adapter**  
Na het scannen van de qr-code wordt het dashboard getoond. Druk op de instellingen zoals dit in onderstaande afbeelding wordt weergegeven.

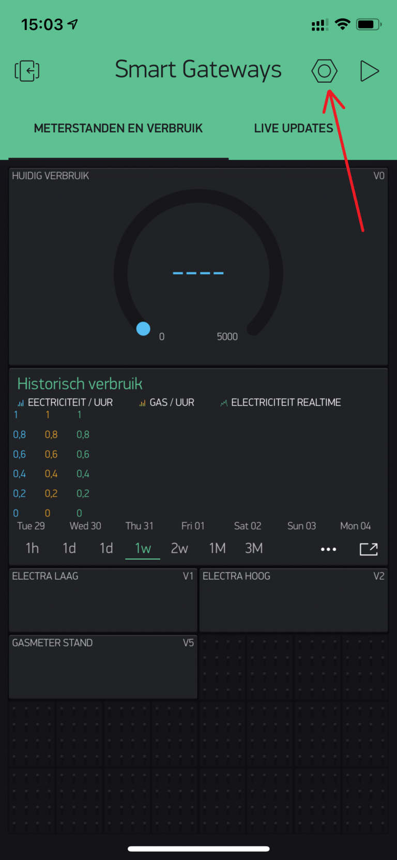
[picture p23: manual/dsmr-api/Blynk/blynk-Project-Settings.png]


Onderstaande scherm wordt dan getoond. Dit scherm bevat AUITH token. Deze is nodig om op te nemen in de P1-adapter.

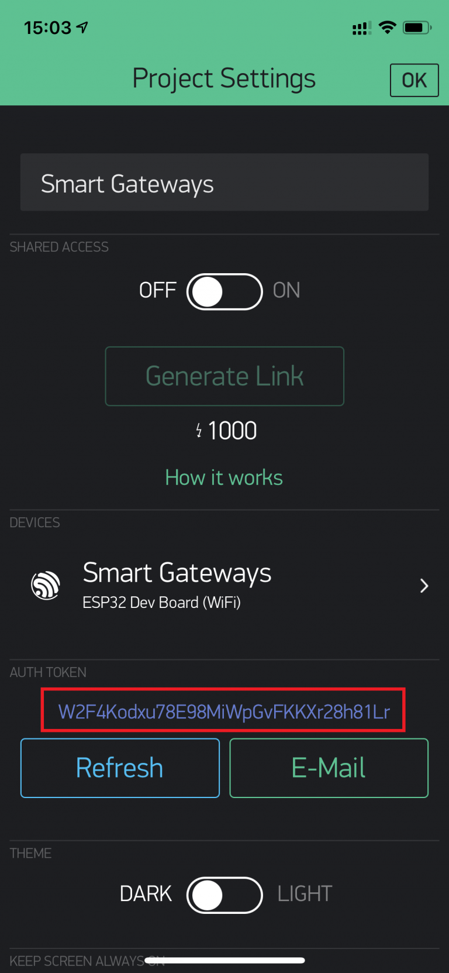
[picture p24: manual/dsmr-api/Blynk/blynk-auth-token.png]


Druk op E-mail knop om de code naar u te laten e-mailen.

**zet auth token in bestand "BlynkSetup" (notepad / kladblok app)**  
De P1 adapter heeft het token nodig om de Blynk app van data te kunnen voorzien. Dit token kan worden opgegeven door een simpel bestandje te maken met de naam "BlynkSetup". Let op de hoofd en kleine letters en GEEN bestands extensie. In dit bestandje wordt het token gekopieerd. 

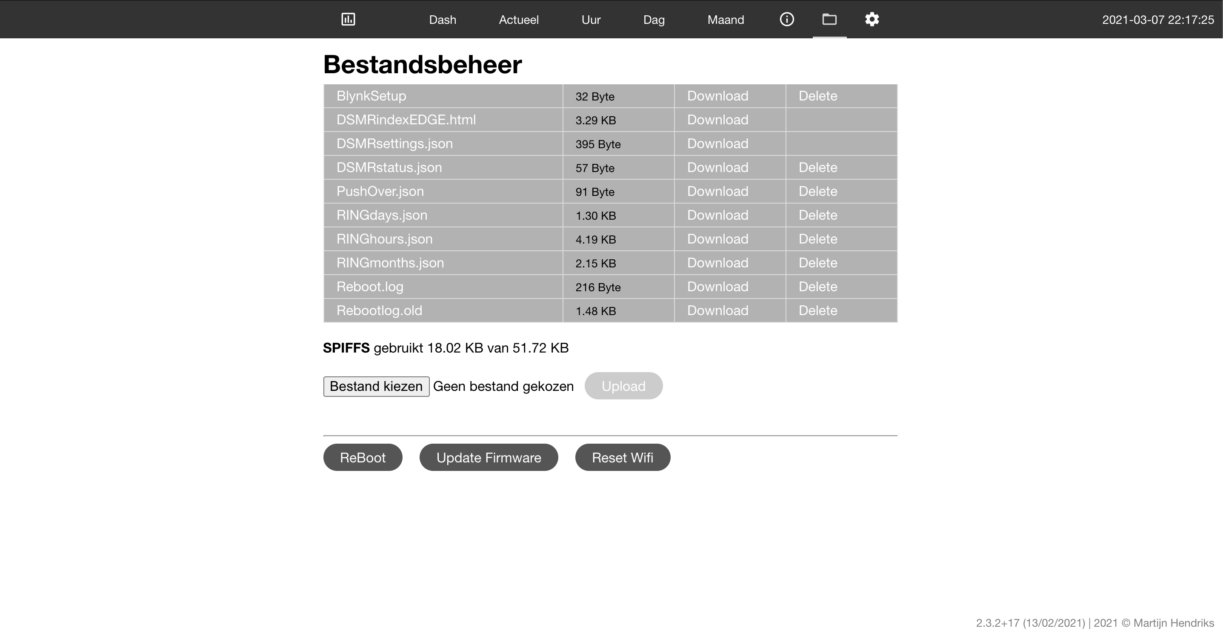
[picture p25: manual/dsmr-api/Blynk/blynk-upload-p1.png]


Via bestandsbeheer (folder icoon rechtsboven) op de p1 adapter (web interface) kan dit bestand worden geupload via bestand kiezen. Na 10 seconden zal de Blynk app aangegeven dat de datafeed actief is. Is na 10 seconden in de Blynk app nog steeds geen data binnen gekomen dan kan er iets mis gegaan zijn met het kopiëren van de AUTH gegevens.

**Blynk interval dataverversing** 
De snelheid waarmee ververst wordt hangt samen met de snelheid waarmee de datagrammen uit de slimme meter gelezen worden. In de standaard configuratie is dat 10 seconden. In de instellingen kan dit worden aangepast naar elk gewenste snelheid.

**Welke gegevens kunnen worden bekeken?**  
De onderstaande gegevens kunnen worden bekeken via de Blynk app.

 veld 	| Omschrijving 							| Eenheid 	| Firmware 
----- 	|------------- 							| ------- 	| -------
V0  	| Actueel elektriciteit verbruik 		| [Watt]	| 2.3.1
V1  	| Meterstand t1 = laag 					| [kWh]		| 2.3.1
V2  	| Meterstand t2 = hoog 					| [kWh]  	| 2.3.1
V3  	| Actuele teruglevering 				| [Watt]  	| 2.3.1
V5  	| Gastellerstand 						| [m3]  	| 2.3.1
V6  	| Meterstand 1  = laag teruglevering  	| [kWh]  	| 2.3.1
V7  	| Meterstand 2  = hoog teruglevering  	| [kWh]  	| 2.3.1
V9  	| Ruw telegram  (werkt nog niet optimaal, app buffer is snel vol)| | 2.3.1
V10 	| Gasverbruik vandaag 					| [m3] 		| 2.3.3
V11 	| Verbruik electra vandaag  			| [kWh] 	| 2.3.3
V12 	| Teruglevering electra vandaag  		| [kWh] 	| 2.3.3

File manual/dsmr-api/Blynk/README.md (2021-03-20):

# **Blynk App**

Deze functie is beschikbaar vanaf release 2.3.1 van de dsmr V2 firmware.

In de Blynk app kunnen diverse gegevens gedeeld worden zodat actuele gegevens overal en altijd zichtbaar zijn. 
Deze gegevens lopen via de Blynk Cloud Service. Er is geen link tussen het soort gegevens en de inhoud omdat het virtuele veldnamen (V1 - V11) zijn maar het is wel goed om te weten dat deze data via dit platform verloopt.

**Blynk app instellen** 

Stap 1: Download de Blynk app uit de app store.

[Blynk voor Android](https://play.google.com/store/apps/details?id=cc.blynk)  
[Blynk voor iOS](https://apps.apple.com/us/app/blynk-iot-for-arduino-esp32/id808760481) 

Stap 2: Instellen van de app

- maak new account (indien u nog geen account heeft)
- start new project in de app
- scan qr code
- copier/e-mail auth token voor in de P1 adapter 
- zet auth token in bestand "BlynkSetup" (notepad / kladblok app)
- upload BlynkSetup bestand naar P1 adapter

**New account**  
Indien u de Blynk app voor eerst gebruikt dan dient u een account aan te maken. 

**Start nieuw project**  
Druk op het scan icoon (rode pijl) in de Blynk app.



**scan qr code**  
Scan onderstaande qr code met de Blynk App.



**copier/e-mail auth token voor in de P1 adapter**  
Na het scannen van de qr-code wordt het dashboard getoond. Druk op de instellingen zoals dit in onderstaande afbeelding wordt weergegeven.



Onderstaande scherm wordt dan getoond. Dit scherm bevat AUITH token. Deze is nodig om op te nemen in de P1-adapter.



Druk op E-mail knop om de code naar u te laten e-mailen.

**zet auth token in bestand "BlynkSetup" (notepad / kladblok app)**  
De P1 adapter heeft het token nodig om de Blynk app van data te kunnen voorzien. Dit token kan worden opgegeven door een simpel bestandje te maken met de naam "BlynkSetup". Let op de hoofd en kleine letters en GEEN bestands extensie. In dit bestandje wordt het token gekopieerd. 



Via bestandsbeheer (folder icoon rechtsboven) op de p1 adapter (web interface) kan dit bestand worden geupload via bestand kiezen. Na 10 seconden zal de Blynk app aangegeven dat de datafeed actief is. Is na 10 seconden in de Blynk app nog steeds geen data binnen gekomen dan kan er iets mis gegaan zijn met het kopiëren van de AUTH gegevens.

**Blynk interval dataverversing** 
De snelheid waarmee ververst wordt hangt samen met de snelheid waarmee de datagrammen uit de slimme meter gelezen worden. In de standaard configuratie is dat 10 seconden. In de instellingen kan dit worden aangepast naar elk gewenste snelheid.

**Welke gegevens kunnen worden bekeken?**  
De onderstaande gegevens kunnen worden bekeken via de Blynk app.

 veld 	| Omschrijving 							| Eenheid 	| Firmware 
----- 	|------------- 							| ------- 	| -------
V0  	| Actueel elektriciteit verbruik 		| [Watt]	| 2.3.1
V1  	| Meterstand t1 = laag 					| [kWh]		| 2.3.1
V2  	| Meterstand t2 = hoog 					| [kWh]  	| 2.3.1
V3  	| Actuele teruglevering 				| [Watt]  	| 2.3.1
V5  	| Gastellerstand 						| [m3]  	| 2.3.1
V6  	| Meterstand 1  = laag teruglevering  	| [kWh]  	| 2.3.1
V7  	| Meterstand 2  = hoog teruglevering  	| [kWh]  	| 2.3.1
V9  	| Ruw telegram  (werkt nog niet optimaal, app buffer is snel vol)| | 2.3.1
V10 	| Gasverbruik vandaag 					| [m3] 		| 2.3.3
V11 	| Verbruik electra vandaag  			| [kWh] 	| 2.3.3
V12 	| Teruglevering electra vandaag  		| [kWh] 	| 2.3.3

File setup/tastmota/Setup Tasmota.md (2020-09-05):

# Setup Tasmota voor de P1 interface
Er zijn een aantal stappen nodig om Tasmota op de p1 adapter te laten draaien.
- Stap 1: Tasmota flashen (of zo geleverd krijgen)
- Stap 2: Tasmota configuratie instellen
- Stap 3: domotica oplossing instellen (bv. OpenHAB, HomeAssistant, ...)

## 1 Tasmota flashen
Dit kan op verschillende manieren. 
Met de Tasmota 8.4.0 versie is het nog niet mogelijk om out of the box de firmware te gebruiken.
Een aanpassing is aangevraagd en zal in een nieuwe versie van tasmota komen te zitten 8.4.1 en hoger.

OF gebruik de aangepaste versie firmware_8_4_0_3_aanpassing.bin in deze folder.

Prik de P1 adapter hierna in de slimme meter en wacht totdat je de tasmota-... adapter in je wifi netwerk ziet.
Klik op dit netwerk en wacht totdat je het instellingenscherm van tasmota ziet om de adapter aan het netwerk te koppelen.
Zoek de P1 module in het netwerk op.

## 2 Tasmota configuratie instellen
In de configuratie van Tasmota geef geef je aan dat je de configuratie wilt terugzetten (Restore).
Gebruik het Config_tasmota_C3C439_1081_8.4.0.3.dmp bestand in deze folder.

## 3 domotica oplossing instellen 
Stel de mqtt host in op de adapter.
Daarna dien je in je domotica oplossing het ontvangen van de berichten in te richten. Hieronder de voorbeelden voor OpenHAB en HomeAssistant.

### OpenHAB

mqtt.things
Heb je al een bridge gedefineerd voeg dan onderstaande toe aan dit bestand

// P1 - slimmemeter Tasmota implementatie
     Thing topic slimmemeter_tas "Slimmemeter" @ "Hal" {
    Channels:
		Type string : p1	"receive data"	[ stateTopic="tele/tasmota_C3C439/RESULT", transformationPattern="JSONPATH:SSerialReceived" ]	
    }
    
in de rules folder maak je een nieuw bestand aan p1-dsmr.rules met onderstaande code
```rule "P2 P"
when
    Item P2 received update
then
	if (P2.state == NULL || P2 == "") return;
    var rawString = P2.state.toString
	//P1_I 		1-0:31.7.0(002*A)
	val rawString3 = transform("REGEX", ".*([0-9]{3}).A.*", rawString)
	if ( rawString3 != NULL && rawString3 !== null && rawString3 != "") { 
		P1_I.postUpdate(rawString3) 
		} 
	//P1_T1		1-0:1.8.1(000013.000*kWh) (Totaal geleverd tarief 1 (nacht))
	 rawString3 = transform("REGEX", ".*1.8.1.([0-9]{6}.[0-9]{3}).kWh.*", rawString)
	if ( rawString3 != NULL && rawString3 !== null && rawString3 != "") { 
		P1_T1.postUpdate(rawString3) 
		} 
	//P1_T2 	1-0:1.8.2(000084.000*kWh) (Totaal verbruik tarief 2 (dag))
	 rawString3 = transform("REGEX", ".*1.8.2.([0-9]{6}.[0-9]{3}).kWh.*", rawString)
	if ( rawString3 != NULL && rawString3 !== null && rawString3 != "") { 
		P1_T2.postUpdate(rawString3) 
		} 
	//P2_GAS 	0-1:24.2.1(191222151005W)(02728.449*m3)
	rawString3 = transform("REGEX", ".*[0-9]{12}.*([0-9]{5}.[0-9]{3}).m3.*", rawString)
	if ( rawString3 != NULL && rawString3 !== null && rawString3 != "") { 
		P1_GAS.postUpdate(rawString3) 
		} 
	// P2_P 		1-0:21.7.0(00.523*kW)
	rawString3 = transform("REGEX", ".*21.7.0.([0-9]{2}.[0-9]{3}).kW.*", rawString)
	if ( rawString3 != NULL && rawString3 !== null && rawString3 != "") { 
		P1_P.postUpdate(rawString3) 
		} 
		//time: 0-0:1.0.0(200716222227S)
	rawString3 = transform("REGEX", ".*1.0.0.([0-9]{12})S.*", rawString)
	if ( rawString3 != NULL && rawString3 !== null && rawString3 != "") { 
		P1_time.postUpdate(rawString3) 
		} 
end

rule "P1 last update"
when
    Item P1_time received update
then
	if (P1_time.state == NULL || P1_time == "") return;
    var rawString = P1_time.state.toString
	val res = String::format("%s-%s-%s %s:%s:%s", rawString.substring(4, 6), rawString.substring(2, 4), rawString.substring(0, 2),rawString.substring(6, 8), rawString.substring(8, 10),rawString.substring(10, 12))
	if ( res != NULL && res !== null && res != "") { 
		P1_tijd.postUpdate(res) 
		} 
end   
``` 

In het .items bestand voeg je de waardes toe die je wilt zien. Hieronder een voorbeeld (dit voorbeeld is voor tasmota + standalone implementatie geschikt).
```
Number P1_P "Actueel vermogen [%s]"	 {channel="mqtt:topic:mosquitto:slimmemeter:P" } 
Number P1_GAS "Gasmeter: [%.1f]"	 {channel="mqtt:topic:mosquitto:slimmemeter:G" }
Number P1_T1 "kWh Teller 1: [%s]"	 {channel="mqtt:topic:mosquitto:slimmemeter:T1" } 
Number P1_T2 "kWh Teller 1: [%s]"	 {channel="mqtt:topic:mosquitto:slimmemeter:T2" } 
Number P1_I "Stroom: [%s]"			 {channel="mqtt:topic:mosquitto:slimmemeter:I" }
Number P1_U "Spanning: [%s]"		 {channel="mqtt:topic:mosquitto:slimmemeter:U" } 
String P1_time "tijd: [%s]" 		 {channel="mqtt:topic:mosquitto:slimmemeter:time" } //dit is de systeemtijd uit de slimmemeter
String P1_tijd "tijd: [%s]"

String P2 "test [%s]"				 {channel="mqtt:topic:mosquitto:slimmemeter_tas:p1" } 
```
In het .sitemap bestand laat je de waardes uit .items terugkomen
```
Frame label="Slimmemeter" {
    Text item=P1_T1 label="kWh Teller Dal: [%.1f kWh]"
    Text item=P1_T2 label="kWh Teller Normaal: [%.1f kWh]"
    Text item=P1_P label="Actuele vermogen: [%.3f kW]"
    Text item=P1_I label="Actuele stroom: [%.0f A]"
    Text item=P1_U label="Actuele Spanning: [%.1f V]"
    Text item=P1_GAS label="Gasmeter: [%.1f m3]"
   	Text item=P1_tijd label="Laatste P1 update: [%s]"
   	Text item=P1_time label="Laatste P1 update: [%s]" //zou je ook weg kunnen laten dit is de ruwe tijd
   	}
```
### HomeAssistant
Work in progress

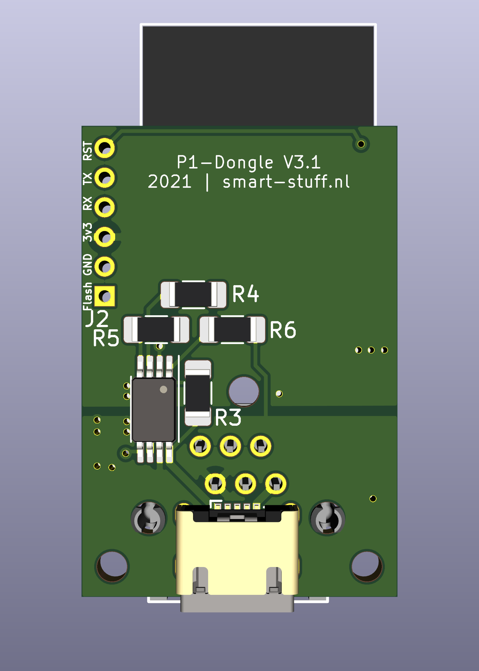
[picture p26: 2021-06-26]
.github/images/v3.1-print-onder.png

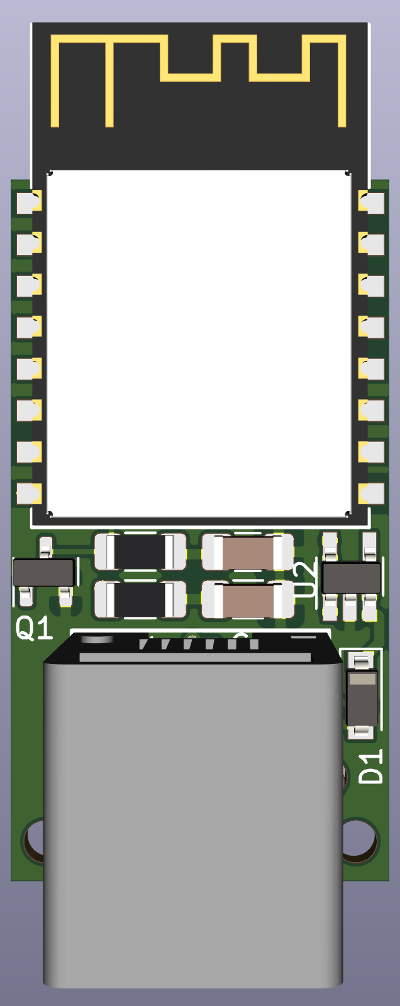
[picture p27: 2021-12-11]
.github/images/v3.3-print-boven.png

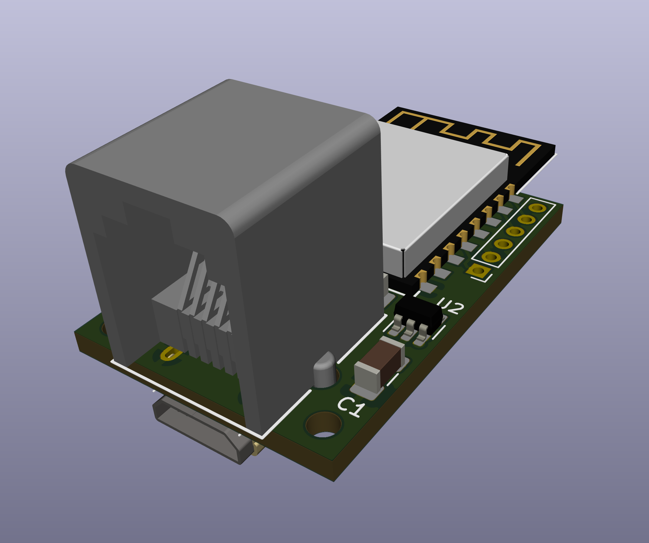
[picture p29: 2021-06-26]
.github/images/v3.1-print-zij.png

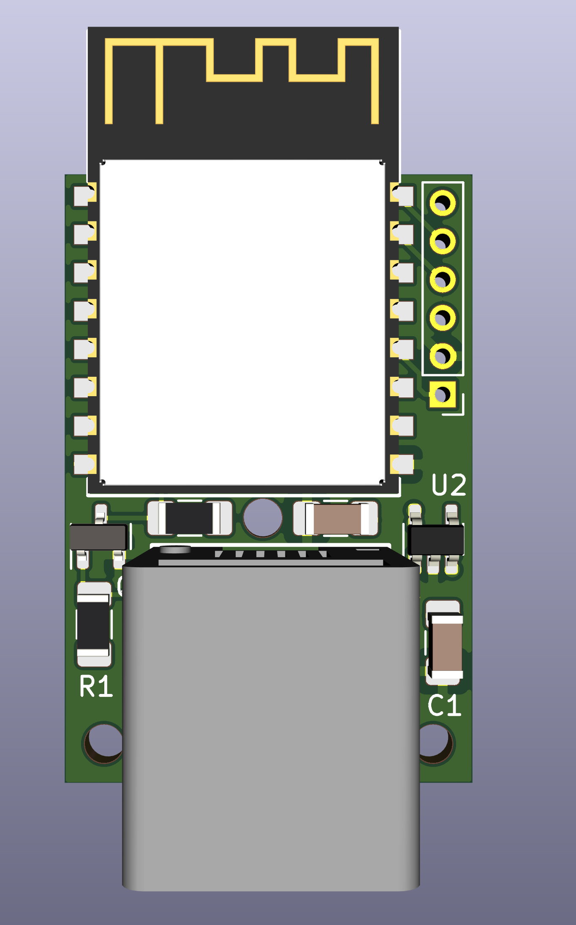
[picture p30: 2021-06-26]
.github/images/v3.1-print-boven.png

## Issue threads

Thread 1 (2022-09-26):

Labels day/night tariff

Draftdog, 2022-09-26:
Hi @mhendriks,

When I connect to the dongle here at home I notice that the day and night tariffs have been switched, i.e. the values correspond to what I know are the opposite values.
Briefly skimming through the source code only the `translateFields` property in `edge/DSMRIndex.js` would need to be updated. Not sure about other places though.

```
var translateFields = [
           [ "author",                    "Auteur" ]
          ,[ "identification",            "Slimme Meter ID" ]
		  ,[ "timestamp",            	  "Tijdcode" ]
          ,[ "p1_version",                "P1 Versie" ]
          ,[ "energy_delivered_tariff1",  "Energie Afgenomen teller 1 - Nacht" ]
          ,[ "energy_delivered_tariff2",  "Energie Afgenomen teller 2 - Dag" ]
          ,[ "energy_returned_tariff1",   "Energie Teruggeleverd teller 1 - Nacht" ]
          ,[ "energy_returned_tariff2",   "Energie Teruggeleverd teller 2 - Dag" ]
```

So in other words, on my device the `tariff1` values correspond to the day tariffs.

Cheers
-- Wouter

mhendriks, 2022-10-06:
Wouter,
T1 = night
T2 = day

Think it is better to omit the day and night indication for EU usage.
NL
T1 = night

BE
T2 = night

Closed 2022-10-06.

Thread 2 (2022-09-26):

Reset Wifi does not seem to work

Draftdog, 2022-09-26:
When using the `Reset Wifi` button on the `Reset en Update` page I'm not getting the expected page:

1. I have the P1 dongle properly working, it says I'm using version `3.5.0+1058 (17/06/2022)`
2. I go to http://dsmr-api.local/#Reset and tap on the `Reset Wifi` Button
3. I'm still able to use the webpage as before, I was expecting to see the screen with which I can configure my network connection
4. the blue led indicator is continuously on, unlike the situation when I first connected the dongle to my network
5. I cannot see the `P1 Dongle` Wifi network
6. software/hardware restarts do not help the situation
7. I tried updating the firmware to version 3.5.1 via the tarball download from this repo's releases, but this did not seem to do anything

mhendriks, 2022-10-06:
thanks for reporting. Well found.
Issue in the 3.5.0 version. Solved in 3.5.1
The 3.5.1 is available as an alpha version.

Closed 2022-10-06.

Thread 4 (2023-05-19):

Home Assistant MQTT DSMR error.

mihaiaka, 2023-05-19:
Hello Martijn,

My home assistant is complaing about the timetag (probably because of the inclusion of the "S" >> "non-numeric value"), as you can see in this HA log:

Logger: homeassistant.components.mqtt.models
Source: components/sensor/__init__.py:583
Integration: MQTT (documentation, issues)
First occurred: 19:16:06 (46 occurrences)
Last logged: 19:20:18

Exception raised when updating state of sensor.dsmr_last_update, topic: 'DSMR-API/timestamp' with payload: b'{"timestamp":[{"value":"230507191952S"}]}'
Exception raised when updating state of sensor.dsmr_last_update, topic: 'DSMR-API/timestamp' with payload: b'{"timestamp":[{"value":"230507191957S"}]}'
Exception raised when updating state of sensor.dsmr_last_update, topic: 'DSMR-API/timestamp' with payload: b'{"timestamp":[{"value":"230507192003S"}]}'
Exception raised when updating state of sensor.dsmr_last_update, topic: 'DSMR-API/timestamp' with payload: b'{"timestamp":[{"value":"230507192009S"}]}'
Exception raised when updating state of sensor.dsmr_last_update, topic: 'DSMR-API/timestamp' with payload: b'{"timestamp":[{"value":"230507192015S"}]}'
Traceback (most recent call last):
  File "/usr/src/homeassistant/homeassistant/components/sensor/__init__.py", line 579, in state
    numerical_value = int(value)
ValueError: invalid literal for int() with base 10: '2023-05-07 19:16:02'

The above exception was the direct cause of the following exception:

Traceback (most recent call last):
  File "/usr/src/homeassistant/homeassistant/components/mqtt/models.py", line 270, in process_write_state_requests
    entity.async_write_ha_state()
  File "/usr/src/homeassistant/homeassistant/helpers/entity.py", line 585, in async_write_ha_state
    self._async_write_ha_state()
  File "/usr/src/homeassistant/homeassistant/helpers/entity.py", line 649, in _async_write_ha_state
    state = self._stringify_state(available)
  File "/usr/src/homeassistant/homeassistant/helpers/entity.py", line 591, in _stringify_state
    if (state := self.state) is None:
  File "/usr/src/homeassistant/homeassistant/components/sensor/__init__.py", line 583, in state
    raise ValueError(
ValueError: Sensor sensor.dsmr_last_update has device class None, state class measurement unit  and suggested precision None thus indicating it has a numeric value; however, it has the non-numeric value: 2023-05-07 19:16:02 (<class 'str'>)

The entity in home assistant, being unable to read that, turns to "unknown", but the log is being flooded with the above error.
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

TELNET-ing to the P1 module, it also logs something about this:
###going on forever like this every 2 seconds:
[Time----][FreeHeap/mBlck][Function----(line):
[13:56:10][  21152| 19840] processSlimm(  57): telegramCount=[118807] telegramErrors=[6] bufferlength=[905]
[13:56:10][  21152| 19840] processTeleg( 103): Telegram[118807]=>DSMRdata.timestamp[230519135611S]

For now, i've disable the "DSMR Last Update" entity so it will stop flooding the HA logs, but it's still filling up the screen on telnet via P1.

Is there something you can assist with from your end?
I'm already on version 3.5.7. (thank you for that)

Looking forward, thank you very much.
Mihai.

mhendriks, 2023-05-20:
The telnet output is normal behaviour. This is the logging. Looking okay.

The b before the payload ( `b'{"timestamp":[{"value":"230507191952S"}]}'` ) is strange. Shouldn't be there.

In the logging it looks like HA parsing the timestamp to an integer value. This will fail. Better is to parse it to a date object like this:

`strptime(value_json.timestamp[0].value[0:12], \'%y%m%d%H%M%S\')`

AllardKatan, 2023-08-09:
I can confirm this issue. Similar error message on my HomeAssistant instance.

mhendriks, 2023-08-13:
issue with the Auto Discovery is solved in release 3.5.9.  Issue raised due to changes in HA updates.

AllardKatan, 2023-11-19:
I was running 3.5.9 for a while and I thought the issue was solved. But after looking into it a bit more, I am still getting a lot of these same error messages. For some reason, some of the messages get through, because I am getting correct values in my energy dashboard, but the update rate seemed slower than what I thought it should be.
I went into the logs and noticed this same error occuring many times.
Then I made things worse by attempting to upgrade to the latest version. I downloaded the latest binary from https://docs.smart-stuff.nl/v/p1-dongle-api/geavanceerd/software-update and installed it via the web interface. Now the dongle has disappeared from my WLAN....

Closed 2025-02-01.

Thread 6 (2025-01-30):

LWT not going to Offline

jeroenst, 2025-01-30:
The LWT topic is Online when the device connects to the mqtt server but never goes to Offline when the ultra mini dongle disconnects.

Version : 4.10.1

mhendriks, 2025-02-01:
thanks sharing. solved in 4.10.2 ... not yet released

Closed 2025-02-01.

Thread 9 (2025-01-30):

Feature request: Add mqtt data

jeroenst, 2025-01-30:
Can the following values be added to mqtt?

Freeram
Uptime
Hostname
Wifi SSID
Wifi Channel
MQTT SSL active
MQTT clientid
MQTT server
MQTT port
MQTT username

(This can also be 1 mqtt message in JSON format)

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

mhendriks, 2025-02-01:
It will put on the backlog of the  new major version (v5 firmware). This version will contain only a couple of mqtt topics with a json payload. The current setup is generating a lot of topics/traffic.

jeroenst, 2025-02-01:
Yeah, I did the same with my esp firmware, each value it's own topic but it creates a lot of packets. Json per category is a much cleaner approach. 👍

mhendriks, 2025-02-01:
:-) it is already available in the current version as hidden feature in the settings.json
By setting the act-json-mqtt value on true one payload will be used for the dynamic data.

"act-json-mqtt":false

mhendriks, 2025-07-05:
Maybe in the new major release. End of this year.

Closed 2025-07-05.

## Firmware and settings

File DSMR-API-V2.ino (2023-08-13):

/*
***************************************************************************  
**  Program  : DSMRloggerAPI (restAPI)
**
**  Copyright (c) 2021 Martijn Hendriks
**
**  TERMS OF USE: MIT License. See bottom of file.                                                            
***************************************************************************      
*      
TODO
- telnet update via windows ... invoeren lukt niet
- Jos: zou je de dag totalen zoals op het dashboard ook via MQTT kunnen exporteren? Gas_dag, Water_dag, Afname_dag, Teruglevering_dag, Afname-Terug_dag
- data voor dag tabel eens per dag
- data voor maand tabel eens per maand
- bugje : 3.5.7 spanning in dash werkt niet meer (ben)
- actueel display teruglevering kleuren (ben)

Arduino-IDE settings for DSMR-logger hardware ESP12S module:

    - Board: "Generic ESP8266 Module" //https://arduino.esp8266.com/stable/package_esp8266com_index.json
    - Flash mode: "QIO"
    - Flash size: "4MB (FS: 1MB OAT:~1019KB)"
    - DebugT port: "Disabled"
    - DebugT Level: "None"
    - IwIP Variant: "v2 Lower Memory"
    - Reset Method: "none"   // but will depend on the programmer!
    - Crystal Frequency: "26 MHz"
    - VTables: "Flash"
    - Flash Frequency: "40MHz"`
    - CPU Frequency: "160MHz"
    - Buildin Led: 2
    - Upload Speed: "460800"                                                                                                                                                                                                                                                 
    - Erase Flash: "Only Sketch"
    - Port: <select correct port>
*/
/******************** compiler options  ********************************************/
//#define SHOW_PASSWRDS             // well .. show the PSK key and MQTT password, what else?
//#define DEBUG_MODE
//#define V2_COMPATIBLE             // Spiffs version firmware 2.x compatible ESP-M(2/3) HARDWARE
//#define NO_HIST

//----- EXTENSIONS
#define HA_DISCOVER
#define ALL_OPTIONS "[CORE]"

#include "DSMRloggerAPI.h"

//===========================================================================================
void setup() 
{
  Serial.begin(115200, SERIAL_8N1);
  pinMode(DTR_ENABLE, OUTPUT);
  pinMode(LED, OUTPUT); //LED ESP12S
  // sign of life
  digitalWrite(LED, LOW); //ON
  delay(1500);
  digitalWrite(LED, HIGH); //OFF
  
  //--- setup randomseed the right way
  //--- This is 8266 HWRNG used to seed the Random PRNG
  //--- Read more: https://config9.com/arduino/getting-a-truly-random-number-in-arduino/
  randomSeed(RANDOM_REG32); 
  
  Debugln(F("\n\n ----> BOOTING....[" _VERSION "] <-----\n"));
  DebugTln(F("The board name is: " ARDUINO_BOARD));

  strcpy(lastReset , ESP.getResetReason().c_str());
  DebugT(F("Last reset reason: ")); Debugln(lastReset);
  
  startTelnet();

//================ Read Persistance Settings ====================
  P1StatusBegin();
  if (P1StatusAvailable()) P1StatusRead(); //load persistant data

//================ FS ===========================================
  if (FS.begin()) 
  {
    DebugTln(F("File System Mount succesful"));
    FSmounted = true;   
  } else {
    DebugTln(F("/!\\File System Mount failed/!\\"));   // Serious problem with FS 

  }

  // set the time to actTimestamp!
  actT = epoch(actTimestamp, strlen(actTimestamp), true);
  P1Status.reboots++;
//  DebugTf("===> actTimestamp[%s]-> nrReboots[%u] - Errors[%u]\r\n\n", actTimestamp, P1Status.reboots, P1Status.sloterrors);                                                                    
  P1StatusWrite();
  P1StatusPrint(); //print latest values
  readSettings(true);
  LogFile("",false); // write reboot status to file
  
//=============start Networkstuff==================================
  
  startWiFi(settingHostname, 240);  // timeout 4 minuten
  startMDNS(settingHostname);

//================ Start MQTT  ======================================

  if ( (strlen(settingMQTTbroker) > 3) && settingMQTTinterval) connectMQTT();

//================ Start HTTP Server ================================

  if (!DSMRfileExist(settingIndexPage, false) ) CreateIndexHtml();

  if (DSMRfileExist(settingIndexPage, false) ) {
    DebugTln(F("File System correct populated -> normal operation!\r"));
    httpServer.serveStatic("/",                 FS, settingIndexPage);
    httpServer.serveStatic("/DSMRindex.html",   FS, settingIndexPage);
    httpServer.serveStatic(_DEFAULT_HOMEPAGE,   FS, settingIndexPage);
  } else DebugTln(F("Oeps! not all files found on File System -> present FSexplorer!\r"));

  setupFSexplorer();
//  delay(500);  
//  DebugTf("Startup complete! actTimestamp[%s]\r\n", actTimestamp);  

//================ Start Slimme Meter ===============================

#ifndef V2_COMPATIBLE  
  ConvRing3_2_0(); //only new modules
#else
  FS.remove("/Reboot.log");      //pre 3.1.1 
  FS.remove("/Reboot.old");      //pre 3.1.1  
  FS.remove("/DSMRstatus.json"); //pre 3.1.1 
#endif

#ifdef NO_HIST
  if ( EnableHistory ) {
    EnableHistory = false;
    FS.remove(RingFiles[0].filename);
    FS.remove(RingFiles[1].filename);
    FS.remove(RingFiles[2].filename);
    FS.remove("/P1_log.old");
    FS.remove("/Reboot.old");      //pre 3.1.1    
    
    writeSettings(); //write to settings file
  }
#endif

 if (EnableHistory) CheckRingExists();

#ifndef DEBUG_MODE 
  DebugTln(F("Swapping serial port to Smart Meter, debug output will continue on telnet"));
  Debug(F("\nGebruik 'telnet "));  Debug (WiFi.localIP());  Debugln(F("' voor verdere debugging"));
  DebugFlush();
  delay(200);
  Serial.swap();
  delay(200);
  DebugTln(F("Enable slimmeMeter...\n"));
  slimmeMeter.enable(true);
#else
  Debug(F("\n!!! DEBUG MODE AAN !!!\n\n"));
#endif

//check old ota url and update with new --- only once at startup
  if( strcmp(BaseOTAurl,"http://smart-stuff.nl/ota/") == 0 ) {
    Debugln(F("Old OTA url available"));
    strcpy(BaseOTAurl, "http://ota.smart-stuff.nl/");
    writeSettings();
  }

} // setup()

//===[ no-blocking delay with running background tasks in ms ]============================
DECLARE_TIMER_MS(timer_delay_ms, 1);
void delayms(unsigned long delay_ms)
{
  CHANGE_INTERVAL_MS(timer_delay_ms, delay_ms);
  RESTART_TIMER(timer_delay_ms);
  while (!DUE(timer_delay_ms))
  {
    doSystemTasks();
  }   
} // delayms()

//==[ Do Telegram Processing ]===============================================================
void doTaskTelegram()
{
  if (Verbose1) DebugTln("doTaskTelegram");
  slimmeMeter.loop(); //voorkomen dat de buffer nog vol zit met andere data
  //-- enable DTR to read a telegram from the Slimme Meter
  slimmeMeter.enable(true); 
}

//===[ Do System tasks ]=============================================================
void doSystemTasks()
{
  slimmeMeter.loop();
  handleSlimmemeter();
  MQTTclient.loop();
  httpServer.handleClient();
  MDNS.update();
  handleKeyInput();
  yield();
} // doSystemTasks()

void loop () 
{  
  //--- verwerk volgend telegram
  if DUE(nextTelegram) doTaskTelegram();

  //--- update upTime counter
  if DUE(updateSeconds) upTimeSeconds++;
  
  //--- do the tasks that has to be done as often as possible
  doSystemTasks(); 

  if ( DUE(StatusTimer) && (telegramCount > 2) ) { 
    P1StatusWrite();
    MQTTSentStaticInfo();
    CHANGE_INTERVAL_MIN(StatusTimer, 23);
  }

  if (UpdateRequested) RemoteUpdate(UpdateVersion, true);

  yield();

} // loop()


/***************************************************************************
*
* Permission is hereby granted, free of charge, to any person obtaining a
* copy of this software and associated documentation files (the
* "Software"), to deal in the Software without restriction, including
* without limitation the rights to use, copy, modify, merge, publish,
* distribute, sublicense, and/or sell copies of the Software, and to permit
* persons to whom the Software is furnished to do so, subject to the
* following conditions:
*
* The above copyright notice and this permission notice shall be included
* in all copies or substantial portions of the Software.
*
* THE SOFTWARE IS PROVIDED "AS IS", WITHOUT WARRANTY OF ANY KIND, EXPRESS
* OR IMPLIED, INCLUDING BUT NOT LIMITED TO THE WARRANTIES OF
* MERCHANTABILITY, FITNESS FOR A PARTICULAR PURPOSE AND NONINFRINGEMENT.
* IN NO EVENT SHALL THE AUTHORS OR COPYRIGHT HOLDERS BE LIABLE FOR ANY
* CLAIM, DAMAGES OR OTHER LIABILITY, WHETHER IN AN ACTION OF CONTRACT, TORT
* OR OTHERWISE, ARISING FROM, OUT OF OR IN CONNECTION WITH THE SOFTWARE OR
* THE USE OR OTHER DEALINGS IN THE SOFTWARE.
* 
***************************************************************************/

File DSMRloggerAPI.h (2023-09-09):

/*
***************************************************************************  
**  Program  : DSMRloggerAPI.h - definitions for DSMRloggerAPI
**  Version  : v3.0.0
**
**  Copyright (c) 2021 Willem Aandewiel / Martijn Hendriks
**
**  TERMS OF USE: MIT License. See bottom of file.                                                            
***************************************************************************      
*/  
#ifndef DSMRloggerAPI_h
#define DSMRloggerAPI_h

#define _DEFAULT_HOSTNAME   "P1-Dongle" 
#define _DEFAULT_MQTT_TOPIC "P1-Dongle/" 
#define _DEFAULT_HOMEPAGE   "/DSMRindexEDGE.html"
#define SETTINGS_FILE       "/DSMRsettings.json"

#ifdef V2_COMPATIBLE
  #define DTR_ENABLE          14 //needed for hardware 3.1 and older
#else 
  #define DTR_ENABLE          -1 //disable
#endif

#define LED                 2
#define HOST_DATA_FILES    "cdn.jsdelivr.net"
#define PATH_DATA_FILES    "https://cdn.jsdelivr.net/gh/mhendriks/DSMR-API-V2@latest/data"

static tm timeinfo;
bool        LEDenabled    = true;

#include "version.h"
#include <TimeLib.h>            // https://github.com/PaulStoffregen/Time
#include <TelnetStream.h>       // https://github.com/jandrassy/TelnetStream/commit/1294a9ee5cc9b1f7e51005091e351d60c8cddecf
#include "safeTimers.h"
#include <ArduinoJson.h>
#include "Debug.h"
#include <EEPROM.h>
WiFiClient  wifiClient;
#include "Network.h"

#ifdef V2_COMPATIBLE
  #define FS SPIFFS
#else
  #include "LittleFS.h"
  #define FS LittleFS
#endif

static      FSInfo fs_info;

//  https://github.com/mrWheel/dsmr2Lib.git             
#include <dsmr2.h>               // commit 0ed3916813850af43200863853bfb4b26e9655eb on 7 juni 2021

P1Reader    slimmeMeter(&Serial, DTR_ENABLE);

enum E_ringfiletype {RINGHOURS, RINGDAYS, RINGMONTHS};

typedef struct {
    char          filename[17];
    int8_t        slots;
    unsigned int  seconds;
    int f_len;
  } S_ringfile;

#ifdef V2_COMPATIBLE
  // pre 3.2.0 versions
  const S_ringfile RingFiles[3] = {{"/RINGhours.json", 48+1,SECS_PER_HOUR, 4287}, {"/RINGdays.json",14+1,SECS_PER_DAY, 1329},{"/RINGmonths.json",24+1,0,2199}}; 
  #define DATA_FORMAT       "{\"date\":\"%-8.8s\",\"values\":[%10.3f,%10.3f,%10.3f,%10.3f,%10.3f]}"
  #define DATA_RECLEN       87  //total length incl comma and new line
#else 
  //vanaf 3.2.0 met watermeter
  //+1 voor de vergelijking, laatste record wordt niet getoond 
  const S_ringfile RingFiles[3] = {{"/RNGhours.json", 48+1,SECS_PER_HOUR, 4826}, {"/RNGdays.json",14+1,SECS_PER_DAY, 1494},{"/RNGmonths.json",24+1,0,2474}}; 
  #define DATA_FORMAT      "{\"date\":\"%-8.8s\",\"values\":[%10.3f,%10.3f,%10.3f,%10.3f,%10.3f,%10.3f]}"
  #define DATA_RECLEN       98  //total length incl comma and new line
#endif

#define JSON_HEADER_LEN   23  //total length incl new line
#define DATA_CLOSE        2   //length last row of datafile


/**
 * Define the DSMRdata we're interested in, as well as the DSMRdatastructure to
 * hold the parsed DSMRdata. This list shows all supported fields, remove
 * any fields you are not using from the below list to make the parsing
 * and printing code smaller.
 * Each template argument below results in a field of the same name.
 */

 /***
  * gekozen om niet alle elementen te parsen.
  * aanname is dat voor 99% van de gebruikers de gasmeter op Mbus1 zit. Alleen deze wordt verwerkt.
  */
 
using MyData = ParsedData<
  /* String */                 identification
  /* String */                ,p1_version
  /* String */                ,p1_version_be
  /* FixedValue */            ,peak_pwr_last_q
  /* TimestampedFixedValue */ ,highest_peak_pwr
  /* String */                ,highest_peak_pwr_13mnd
  /* String */                ,timestamp
  /* String */                ,equipment_id
  /* FixedValue */            ,energy_delivered_tariff1
  /* FixedValue */            ,energy_delivered_tariff2
  /* FixedValue */            ,energy_returned_tariff1
  /* FixedValue */            ,energy_returned_tariff2
  /* String */                ,electricity_tariff
  /* FixedValue */            ,power_delivered
  /* FixedValue */            ,power_returned
//  /* FixedValue */            ,electricity_threshold
//  /* uint8_t */               ,electricity_switch_position
//  /* uint32_t */              ,electricity_failures
//  /* uint32_t */              ,electricity_long_failures
//  /* String */                ,electricity_failure_log
//  /* uint32_t */              ,electricity_sags_l1
//  /* uint32_t */              ,electricity_sags_l2
//  /* uint32_t */              ,electricity_sags_l3
//  /* uint32_t */              ,electricity_swells_l1
//  /* uint32_t */              ,electricity_swells_l2
//  /* uint32_t */              ,electricity_swells_l3
  /* String */                ,message_short
  /* String */                ,message_long
  /* FixedValue */            ,voltage_l1
  /* FixedValue */            ,voltage_l2
  /* FixedValue */            ,voltage_l3
  /* FixedValue */            ,current_l1
  /* FixedValue */            ,current_l2
  /* FixedValue */            ,current_l3
  /* FixedValue */            ,power_delivered_l1
  /* FixedValue */            ,power_delivered_l2
  /* FixedValue */            ,power_delivered_l3
  /* FixedValue */            ,power_returned_l1
  /* FixedValue */            ,power_returned_l2
  /* FixedValue */            ,power_returned_l3
  /* uint16_t */              ,mbus1_device_type
  /* String */                ,mbus1_equipment_id_tc
  /* String */                ,mbus1_equipment_id_ntc
  /* uint8_t */               ,mbus1_valve_position
  /* TimestampedFixedValue */ ,mbus1_delivered
  /* TimestampedFixedValue */ ,mbus1_delivered_ntc
  /* TimestampedFixedValue */ ,mbus1_delivered_dbl
  /* uint16_t */              ,mbus2_device_type
  /* String */                ,mbus2_equipment_id_tc
  /* String */                ,mbus2_equipment_id_ntc
  /* uint8_t */               ,mbus2_valve_position
  /* TimestampedFixedValue */ ,mbus2_delivered
  /* TimestampedFixedValue */ ,mbus2_delivered_ntc
  /* TimestampedFixedValue */ ,mbus2_delivered_dbl
  /* uint16_t */              ,mbus3_device_type
  /* String */                ,mbus3_equipment_id_tc
  /* String */                ,mbus3_equipment_id_ntc
  /* uint8_t */               ,mbus3_valve_position
  /* TimestampedFixedValue */ ,mbus3_delivered
  /* TimestampedFixedValue */ ,mbus3_delivered_ntc
  /* TimestampedFixedValue */ ,mbus3_delivered_dbl
  /* uint16_t */              ,mbus4_device_type
  /* String */                ,mbus4_equipment_id_tc
  /* String */                ,mbus4_equipment_id_ntc
  /* uint8_t */               ,mbus4_valve_position
  /* TimestampedFixedValue */ ,mbus4_delivered
  /* TimestampedFixedValue */ ,mbus4_delivered_ntc
  /* TimestampedFixedValue */ ,mbus4_delivered_dbl
>;

const PROGMEM char *flashMode[]    { "QIO", "QOUT", "DIO", "DOUT", "Unknown" };
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

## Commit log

2021-04-28 mqtt topics
    [mqtt-berichten.xlsx]
2021-05-13 dsmr-be fixes + small code refact
    [DSMR-API-V2.ino, DSMRloggerAPI.h, SlimmeMeter.ino]
2021-10-30 bugs + mqtt update
    [DSMR-API-V2.ino, DSMRloggerAPI.h, FSexplorer.ino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]
2021-11-06 watersensor + bugfixes 3.2.0
    [DSMR-API-V2.ino, DSMRloggerAPI.h, JsonCalls.ino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]
2021-12-01 NTP + case v3.3
2021-12-08 v3.3 case
    [v3.3 boven.stl, v3.3 onder.stl]
2021-12-15 case + watermtr
    [V3.3_onder_usb.stl]
2022-01-12 front-end bugfixes (uitlijning dash, vreemde tekens update pagina)
    [DSMR-API-V2.ino]
2022-01-21 code cleanup en kleine bugfixes
    [DSMR-API-V2.ino, DSMRloggerAPI.h, FSexplorer.ino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]
2022-02-04 Water sensor changes
2022-02-26 easy Arduino IDE handling
2022-03-09 optimalisatie + fix waterlezer
    [DSMR-API-V2.ino, DSMRloggerAPI.h, TelnetMenu.ino]
2022-03-19 HA Auto discovery fix
    [DSMR-API-V2.ino, MQTT.ino]
2022-03-21 update manual linkjes naar de dongle
2022-04-26 remove old casing
    [P1_3.1_boven_v17.stl, P1_3.1_onder_USB_v17.stl, P1_3.1_onder_v17.stl]
2022-05-19 update case v.3.6
    [3.6_onder.stl, v3.6 boven.stl]
2022-06-12 update dsmr 2.2 HA sensor
2022-06-17 3.5.0 fixes and updates
    [DSMR-API-V2.ino, DSMRloggerAPI.h, FSexplorer.ino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]
2022-06-19 migratie documentatie naar gitbook
    [mqtt-berichten.xlsx]
2022-07-06 fix dashboard no voltage
2023-01-10 HA auto disc device name in topic
2023-01-10 fix file system type
    [Helper.ino]
